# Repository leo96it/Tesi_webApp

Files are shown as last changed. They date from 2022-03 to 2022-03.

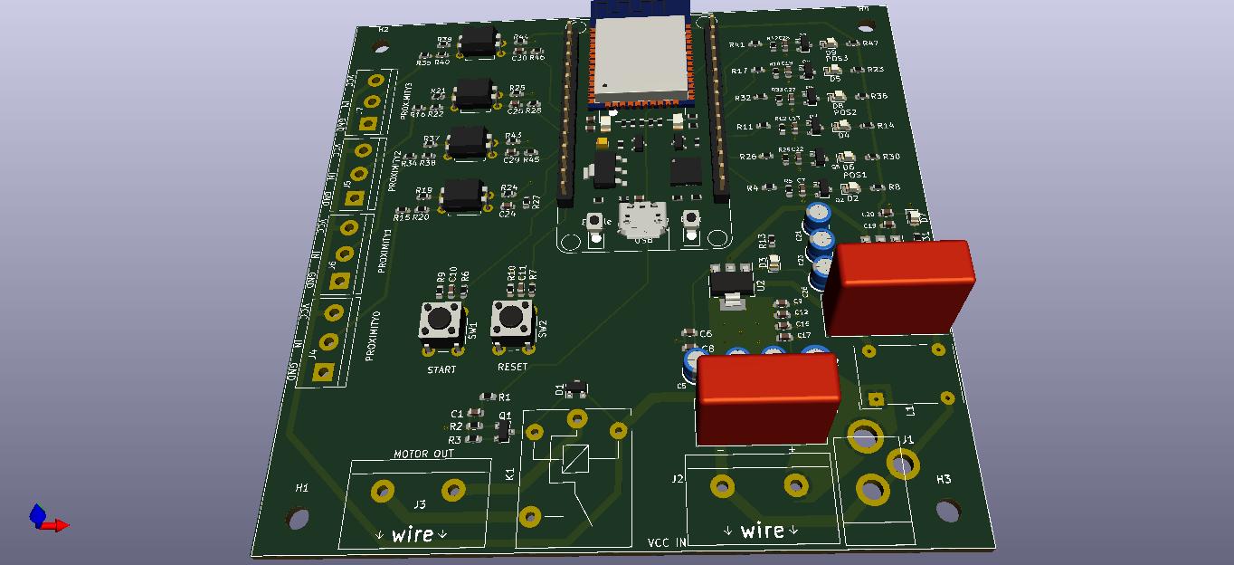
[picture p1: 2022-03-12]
Hardware/ESP32_client/ESP32_client_pcb.jpg

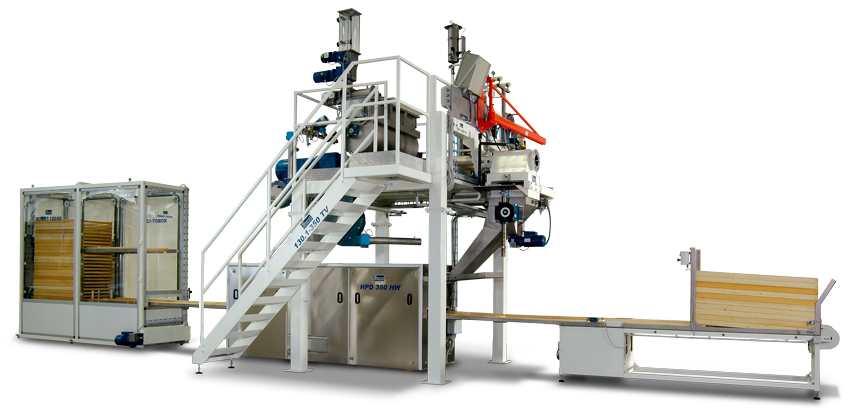
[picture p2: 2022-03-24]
Frontend/angular-app/src/assets/machineryImage/005fewe.png

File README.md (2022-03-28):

# Tesi_webApp

This project was made for the degree in computer engineering at Uninettuno.
It consist of a web server with a backend server, a mysql database and frontend web site. The server receive data from several hardware clients, based on ESP8266 or ESP32 microcontroller.

## Hardware - build with Arduino IDE v1.8.5 and KiCad v5

To run the hardware part, first you need to insert your wifi `SSID` and `password`, then you need to change the `serverURL` variable to match your local IP address.
Finally you can boot the firmware onto the ESP8266 devboard.
ATTENTION: the Arduino IDE require the download of card manager for ESP32 and ESP8266.

## Database - build with MySQL v8.0.28

Download MySQL with the MySQL installer (Windows) from:  https://dev.mysql.com/downloads/installer/.
Create the database called `ESP32_plant1` to match the variable `dbname` in config.json (backend).

## Server - build with NodeJS v14.17.5

Download all the module with `npm i` and start the MYSQL80 system variable. Then run `npm start`.

## Frontend - build with Angular CLI v13.0.3, NPM 6.14.14 and Grafana

First you need to set the Grafana dashboard, follow the PDF file `Elaborato finale - Barea Leonardo` in Extras folder, for the procedure and `query-Grafana` in Database folder for the query from Grafana to MySQL.
Run `ng serve` for a dev server. Navigate to `http://localhost:4200/`. The app will automatically reload if you change any of the source files.

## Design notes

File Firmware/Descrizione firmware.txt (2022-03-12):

Simulazione di uno scenario industriale, con sensori vari.

1. Ad inzio linea è presente un proximity che rileva la presenza o meno del pezzo

2. L'avvia del ciclo di produzione della linea è fatto tramite pulsante START

3. Per ogni stazione sarà presente un proximity per rilevare se il pezzo è arrivato nella stazione ed iniziare quindi la lavorazione

4. La lavorazione è attualmente simulata con un generatore di numeri casuali, il quale simula un PASS/FAIL della lavorazione 

5. In ogni stazione saranno presenti 2 led, verde (tutto ok) e rosso (lavorazione con errori)

6. I led verdi lampeggerenno, tutti: se il pezzo si trova nella postazione 0, ultimi 2: se il pezzo si trova nella postazione 1, solo ultimo: se il pezzo si trova nella postazione 2, nessuno: se il pezzo ha terminato tutto il ciclo e ritorna nella postazione 0.
Ogni volta che il pezzo attraversa una postazione il relativo led diventerà verde fisso se la lavorazione è andata a buon fine o rosso fisso (con relativo blocco impianto) se c'è stato qualche errore

7. Se la lavorazione va in errore si prevede che l'operatore sistemi l'errore e poi tramite pulsante RESET faccia ripartire l'impianto

8. I dati vengono inviati al server ad ogni PASS/FAIL oppure all'uscita del pezzo dalla linea

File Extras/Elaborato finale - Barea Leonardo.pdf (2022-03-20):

## UNIVERSITÀ TELEMATICA INTERNAZIONALE

## UNINETTUNO

## FACOLTÀ DI INGEGNERIA

## Corso di Laurea Triennale in

## Ingegneria Informatica

## ELABORATO FINALE

in

## Ingegneria del software e programmazione ad oggetti

## Monitoraggio di sistemi di produzione industriale, in ambito industria 4.0, attraverso dispositivi IoT

RELATORE | CANDIDATO
Prof.ssa Patrizia Grifoni | Leonardo Barea

### CORRELATORE Prof. Mauro Mazzei

### ANNO ACCADEMICO 2020/2021

i

ii

Con la presente volevo spendere qualche riga per ringraziare tutti coloro che mi sono stati vicini e mi hanno supportato in questo lungo percorso durato tre anni fatto di fatiche e gioie che hanno portato oggi a diventare ciò che sono.

Prima di tutti, vorrei ringraziare la mia compagna Elena che mi ha supportato lungo tutto il percorso, aiutandomi e condividendo insieme a me le gioie degli esiti degli esami e trovando sempre le parole giuste per supportarmi durante i momenti più duri. Grazie a te ho imparato che ogni esame può essere superato, anche quando sembra una montagna insormontabile.

Un ringraziamento va anche alla mia famiglia per avermi sostenuto nella decisione di intraprendere questo percorso di studio e portarlo a termine nel migliore dei modi.

Infine vorrei ringraziare due colleghi di corso, Nicholas e Giampiero, i quali hanno fornito un preziosissimo aiuto alla realizzazione del progetto e con i quali ho avuto il piacere di studiare assieme, portando a casa risultati oltre le aspettative.

Questo percorso mi ha permesso di ritrovare la voglia di studiare, la voglia di imparare, ma soprattutto mi ha permesso di capire che con forza e tanta volontà anche le cose più difficili possono essere superate.

iii

## Indice

iv

v

## Sommario

L’industria nel corso degli anni è stata oggetto di diverse innovazioni, ed insieme ad altri settori,

l’industria riveste un ruolo fondamentale nella vita di ogni persona, direttamente o

indirettamente.

Allo stesso modo l’informatica, settore molto più “giovane” rispetto all’industria, è uno tra quelli più importanti al giorno d’oggi. È il settore che ha visto un incremento esponenziale

dell’innovazione, con una pendenza più ripida rispetto a tutti gli altri settori, passando dalla

gestione di pochi bit negli anni ’50 a milioni di miliardi di bit di oggi.

Questo sviluppo così repentino ha portato l’informatica ad evolversi non solo in verticale (dove

ad un certo punto lo sviluppo è, per forza di cose, rallentato), ma anche in maniera, così

trasversale, da arrivare in tutti i settori, uno tra tutti l’industria.

L’informatica applicata agli oggetti prende il nome di IoT (Internet of Things), ovvero internet

delle cose, mentre in particolare l’informatica legata all’industria prende il nome di IIoT

(Industrial Internet of Things), dall’altro lato invece l’industria che integra sistemi cibernetici,

informatici e connessi, si racchiude all’interno dell’ Industria 4.0.

L’industria 4.0 si basa sul fatto che, se è possibile “connettere” un oggetto di uso comune, come

un orologio, una sveglia, allo stesso modo è possibile connettere anche sistemi più complessi

come, macchinari, robot e utensili.

Il progetto prevede la creazione di un web server completo, fornito di una parte back-end ed una

front-end, per il monitoraggio di impianti di produzione, attraverso un sito dedicato.

Il seguente elaborato ha lo scopo di analizzare nel dettaglio l’implementazione pratica e gli

aspetti fondamentali delle tecnologie utilizzate, nonché fornire un valido supporto al lettore per

la comprensione e la riproduzione dello stesso.

Nel secondo capitolo vengono trattate le tecnologie software utilizzate per la realizzazione del

progetto. In particolare vengono trattati i software utilizzati per ogni livello applicativo, partendo

dall’hardware è stato utilizzato Kicad, software open source, per la schematizzazione e

realizzazione di schede elettroniche (PCB) con strumenti professionali. Permette di generare dei

file Gerber (file contenenti le posizioni dei fori, del layout, dei componenti, il numero di

layer…), con i quali il produttore di schede è in grado di poter poi produrre i PCB.

Arduino IDE, ambiente di sviluppo per l’omonima scheda di sviluppo (o similari), anch’esso

open source, permette la programmazione di microcontrollori della famiglia Atmel o Espressif

vi

(come nel caso del progetto in essere), attraverso un’interfaccia semplice con il supporto di una

community online molto attiva, in linguaggio Wiring.

NodeJS è la piattaforma utilizzata per lo sviluppo del livello back-end, il server. Anch’esso

open-source, sviluppato in tempi recenti, permette, attraverso il motore V8 di Chrome,

l’esecuzione di codice Javascript al di fuori del browser.

MySQL è il DBMS (Data Base Management System) utilizzato per la memorizzazione dei dati

di produzione. Si avvale di tabelle, attraverso le quali è possibile instaurare delle relazioni

semantiche tra diversi attributi della tabella stessa o di altre tabelle.

Angular, framework anch’esso opensource, per la realizzazione di applicativi web, basati su

architettura a pagina singola (single page application), attraverso la quale tutto risiede in

un’unica pagina ed è il contenuto all’interno di essa a cambiare e non la pagina stessa. In questo

modo è possibile creare applicazioni più veloci dove soltanto alcune parti della pagina cambiano

mentre le altre rimangono invariate.

Github è un servizio di repositoring, gratuito, all’interno del quale è possibile caricare del

software (o anche solo parti di codice), per lavorare in team, rendere pubblico il codice scritto, o

più semplicemente avere un “contenitore” (repository) remoto del proprio codice, accessibile

dovunque. Con Github è possibile anche tenere traccia delle modifiche.

Grafana, applicazione web gratuita, permette di accedere a diversi database o sistemi di backend

per fornire una rappresentazione grafica dei dati in essi contenuti.

Grafana permette di accedere direttamente al database attraverso delle query, permette di

scegliere tra diversi grafici molto accattivanti e ben fatti e lavorare sul layout di questi.

Nel terzo capitolo è stato discusso lo scenario d’uso e le caratteristiche del progetto, in

particolare il progetto è stato articolato in modo da essere quanto più scalabile possibile e

permette di agire su ogni livello implementativo senza dover necessariamente stravolgere gli altri

livelli. Una delle caratteristiche principali, è stata proprio la possibilità di rendere il progetto

open-source e accessibile a chiunque lo volesse consultare e migliorare, il tutto accessibile sul

repository pubblico su Github.

Gli scopi principali del progetto sono quelli di garantire manutenzione, efficienza e risparmio. Il

tutto è reso possibile dalle scelte progettuali effettuate, dal know-how acquisito in ambito

industriale e dalle problematiche riscontrate in macchinari di produzione industriale.

vii

Il fine è appunto quello di garantire un maggior controllo sulla produzione per poter intervenire

prontamente sui problemi che si presentano ed avere quindi costi di produzione più bassi, minor

numero di fermi macchina, maggiore autonomia e programmazione delle manutenzioni.

Nei capitoli successivi vengono descritti nel dettaglio le parti di codice più salienti, necessarie

per la comprensione del funzionamento del progetto stesso, il quale prevede più livelli

implementativi:

Il primo è quello hardware, dove un microcontrollore si occupa della raccolta dei dati di

produzione ed invia il tutto in formato JSON al server tramite il protocollo HTTP, il server

recupera i dati, li spacchetta e salva ogni dato ricevuto in un database MySQL. Il sito costruito in

Angular effettuerà delle richieste cicliche (polling) al server il quale risponderà fornendo i dati di

produzione che verranno successivamente mostrati attraverso un browser. Questi dati saranno

visualizzabili in tempo reale, con questi che vengono aggiornati costantemente, oppure sarà

possibile visionarli in uno storico con grafici e diagrammi temporali.

Le possibilità di sviluppo di questo progetto sono pressoché illimitate, per come è stato costruito,

il sito può essere integrato con una sezione di login, è possibile implementare un sistema di

notifica Telegram o mail, è possibile standardizzare il firmware in modo che questo possa

comunicare attraverso un protocollo standard, il MODBUS RTU, con i PLC installati sui

macchinari, in questo modo è possibile monitorare la produzione senza nemmeno dover

modificare l’impianto od i macchinari già presenti.

L’informatica, rende oggi possibile molte delle cose che un tempo erano solo utopie, basta

soltanto un po’ di fantasia, di spirito critico e di tanto studio!

## 1 Introduzione

Negli ultimi anni lo sviluppo legato ad internet ed alle aziende ICT ha visto una crescita non più

soltanto verticale, ovvero legato a determinati campi, ma anche orizzontale, vedendo settori

come l’agricoltura e l’industria sempre più a stretto contatto con quello che è il mondo di

internet. Un po’ per moda, un po’ per scopi effettivamente pratici, ad oggi le aziende stanno

cercando di mettersi al pari con quello che è il progresso tecnologico.

A favore di questo processo di transizione, il Governo, ha messo e sta mettendo, in atto delle

misure volte ad agevolare le aziende stesse ed in particolare le PMI, le quali costituiscono la gran

parte delle aziende italiane, che senza agevolazioni o incentivi difficilmente sarebbero propense

(o meglio in grado) di affrontare i costi di un tale cambiamento. Di fatti si è di fronte a quella che

ormai viene definita 4° rivoluzione industriale.

Negli ultimi 15 anni, si è visto un’importante balzo in avanti anche per quanto riguarda le

tecnologie di internet. Sono infatti nati numerosi framework e linguaggi che prima non

esistevano e con loro si sono quindi incrementate le possibilità di nuovi sviluppi. Basti pensare

che senza javascript le pagine sarebbero ancora statiche o con limitata dinamicità.

L’IoT (Internet of Things) o meglio definito “internet delle cose” è alla base di questo sviluppo e

questo progresso tecnologico che vede interessati sempre più settori e campi d’applicazione.

Ormai risulta veramente economico implementare, a livello hardware, un modulo

Bluetooth/WiFi, per cui ogni dispositivo, elettrodomestico, capo d’abbigliamento ecc ad oggi

può essere connesso ad internet.

L’IoT, quindi, è approdato anche nell’industria e nella robotica al fine di migliorare ed

incrementare la produzione, nonché per garantire una gestione più accurata della qualità.

Lo scopo del progetto è quello di mostrare un esempio di applicazione dell’IoT in ambito

industriale.

Il progetto prevede tutti i livelli d’implementazione di un caso reale di una linea di produzione

industriale con più postazioni, dove l’operatore inserisce il pezzo grezzo da lavorare nella prima

postazione e preme il pulsante di start. Da quel momento vengono azionati i nastri automatici

che porteranno il pezzo da lavorare nelle varie postazioni. Ad ogni postazione sono presenti una

serie di sensori, attuatori e attrezzi per la lavorazione del pezzo e per il controllo dei vari

parametri di lavorazione (quote, quantità di olio, temperatura…).

Quindi passando all’hardware, si è progettato e implementato il circuito elettronico al quale è

collegato il microcontrollore ESP32 (client) il quale, attraverso un firmware apposito, elabora i

diversi dati di produzione/posizione del pezzo e parametri di lavorazione e li invia al server

NodeJS attraverso una chiamata HTTP POST.

Successivamente il server che è in ascolto, recepisce il dato inviato da ESP32 (nel caso di più

ESP32 ognuno sarà un client e tutti invieranno i dati allo stesso indirizzo del server) ed andrà a

salvare questi dati in un database MySQL.

Per la parte di front-end è stato utilizzato il framework Angular, il quale attraverso un’operazione

di polling effettua delle chiamate HTTP GET cicliche al server per tenere i dati costantemente

aggiornati. Infine, nella parte di front-end è stato utilizzata Grafana, un’applicazione web per la

creazione di grafici, la quale effettua direttamente delle query al database per i dati da graficare.

### 1.1 Industria 4.0

Questo rappresenta il tema principale dell’elaborato e rappresenta anche uno dei temi principali

dell’innovazione tecnologica che l’Italia sta portando avanti con la transizione 4.0.

Con industria 4.0 si va ad identificare quella che viene chiamata quarta rivoluzione industriale,

ovvero quella che integra internet ai processi produttivi al fine di migliorare le condizioni di

lavoro, creare nuovi modelli di business, aumentare la produttività degli impianti e migliorare la

qualità dei prodotti.

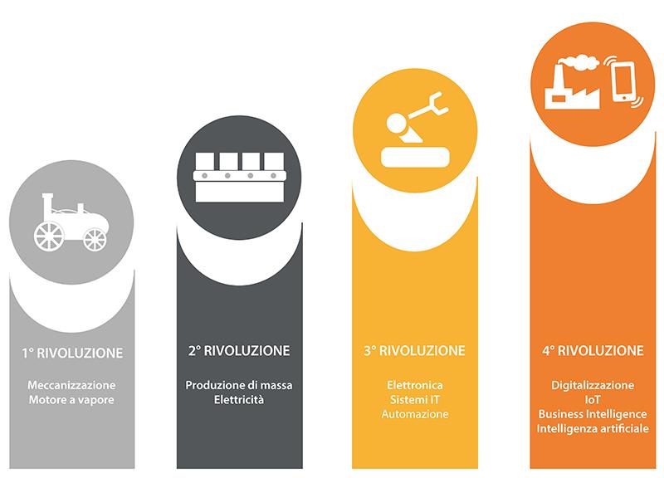
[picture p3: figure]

Figura 1.1: Le quattro rivoluzioni industriali nella storia

### 1.1.1 Industria 4.0 nel mondo

A livello mondiale, il MISE, cita alcune iniziative messe in atto da diversi paesi.

La Francia, ad esempio, ha messo in atto una serie di finanziamenti, prestiti agevolati ed

incentivi per consentire alle aziende di effettuare la transizione.

In Germania, oltre ai finanziamenti alle imprese, è in fase di approvazione dal Governo una serie

di agevolazioni per investire nelle start-up, spesso iniziatrici di innovazioni tecnologiche

importanti.

In Olanda si sta lavorando ad un approccio “network centric” in cui il sistema industriale

tradizionale si combina con le organizzazioni scientifiche e di ricerca nonché con le istituzioni

Governative.

### 1.1.2 Industria 4.0 in Italia

A livello internazionale invece, il Governo, ha dettato una serie di linee guida per consentire alle

imprese di effettuare la transizione tecnologica nel migliore dei modi:

- Neutralità tecnologica
- Operare con azioni orizzontali e non di settore (verticali)
- Orientare strumenti esistenti per favorire il salto tecnologico

Tutte linee guida, basate sulle caratteristiche del settore industriale italiano.

In particolare come nel resto del mondo il piano nazionale prevede degli investimenti alle imprese private ed alle start-up, ma non solo, in quanto lo sviluppo in sé parte dalla scuola. È

così che il Governo Italiano, investe nelle competenze, quindi in progetti di Scuola Digitale,

percorsi Universitari e ITS, dottorati e ricerca…, tutto questo rientra nel Piano Nazionale

Industria 4.0.

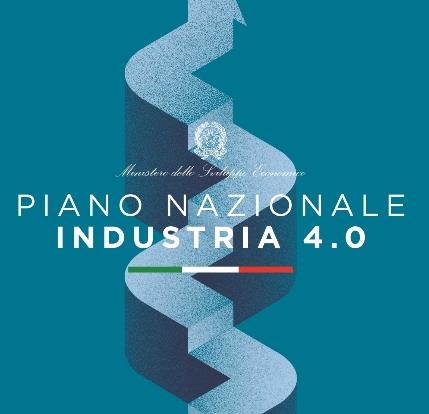
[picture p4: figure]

Figura 1.2: Prima pagina della presentazione "Piano Nazionale Industria 4.0"

### 1.2 Web application

L’altro tema principale di questo elaborato sono le web application. Molto brevemente una web

application, come dice il nome, è un’applicazione (o un insieme di applicazioni) accessibile via

web, quindi attraverso internet.

La maggior parte di queste applicazioni utilizzano come terminali i browser, i quali permettono

lo scambio di dati attraverso protocolli di rete standard, con server remoti i quali contengono i

dati e le pagine dell’applicazione stessa.

Le web application stanno, via a via, diventando sempre più presenti nell’immaginario collettivo

e questo è dovuto al fatto che queste non devono avere un supporto per una specifica

piattaforma, bensì basta un accesso ad internet, un browser ed il gioco è fatto.

In genere una web app si compone di più livelli, per renderla quanto più scalabile possibile,

generalmente si trova un front-end, che è il livello più alto, in cui i dati vengono mostrati

all’utente con l’utilizzo di grafica, immagini, video e suoni secondo lo stile definito dal designer.

A livello più basso troviamo un back-end, che è il nodo centrale, quella parte che consente la

gestione e la manipolazione dei dati e si occupa di gestire le richieste del front-end. Facendo

riferimento a questo elaborato, si trova anche un livello di archiviazione, in cui un database

memorizza tutti i dati che verranno inviati e gestiti dal back-end.

### 1.2.1 Protocollo HTTP

HTTP, ovvero Hyper Text Transfer Protocol, è il protocollo principale per lo scambio di dati sul web. È un linguaggio di testo (ipertesto) che lavora con un’architettura di tipo client-server, in

cui un client effettua una richiesta (request) al server e questo gli risponde con la risorsa cercata

(response).

Una richiesta HTTP generalmente è composta in questo modo:

Figura 1.3: Struttura di una richiesta HTTP

Dove l’URI (Uniform Resource Identifier) è una stringa che identifica in modo univoco una

risorsa.

Il metodo (method), è la parte più importante. Consente di specificare il tipo di richiesta da

effettuare al server da parte del front-end (ad esempio). Qui vengono citati soltanto alcuni dei

metodi presenti e più nel dettaglio quelli utilizzati nel progetto:

- GET: è il metodo più utilizzato dal front-end e serve per recuperare una risorsa dal

server. Nel progetto è utilizzato per la richiesta dei dati da visualizzare sulla pagina web.

- POST: è un metodo che serve per inviare delle risorse al server. Potrebbe essere utilizzato

per inviare i dati di un form dal front-end al server, ma nel progetto è stato utilizzato per

inviare i dati dalla scheda hardware al server.

- DELETE: è un metodo utilizzato per eliminare una risorsa dal server (nel progetto non

viene utilizzato).

Version rappresenta la versione del protocollo HTTP utilizzato. Ad oggi la versione più recente è

la 3.0, risalente al 2018/2019.

L’header contiene una serie di meta informazioni utili per il coordinamento tra client e server

(come ad esempio lo status code, la lunghezza del pacchetto…).

Infine body è il corpo della richiesta HTTP, ovvero quella che conterrà le informazioni.

### 1.2.2 Client-Server

La maggior parte delle applicazioni web, si basano sul modello architetturale client-server, in cui

uno o più client si collegano ad internet e tramite un determinato protocollo (nel progetto è stato

utilizzato il protocollo HTTP visto precedentemente) effettuano delle richieste al server e questo

vi risponde.

Esistono due tipologie di implementazione di un modello client-server in funzione del numero di

livelli su cui l’applicazione è costruita:

- 2-tier: basata su due livelli, il client si connette direttamente con il server;
- 3-tier: nel client sono presenti due livelli, uno che si occupa di gestire la comunicazione

con il server, mentre la visualizzazione dei dati è in un livello a parte (livello thin client).

Figura 1.4: Struttura modello client - server

### 1.3 Internet of things

Internet of things tradotto sta per “internet delle cose”, è quella categoria di oggetti di un

qualsiasi ambito, che in qualche modo sono “connessi”, ovvero presentano una connessione ad

internet.

Questi dispositivi ormai si trovano in ogni cosa, dall’agricoltura, alla domotica, nell’automotive

e nell’industria. Con pochi Euro o addirittura meno è possibile acquistare delle schede di

sviluppo (development board) con a bordo un microcontrollore e dei componenti in grado di

collegarsi al wifi e quindi di inviare e ricevere dati attraverso internet.

La particolarità di questi dispositivi è che sono davvero piccolissimi, alcuni di questi sono grandi

come una moneta e questo permette di integrarli in qualsiasi dispositivo, come orologi, scarpe,

auto e tutto ciò che si vuole.

Il basso costo e le dimensioni ridotte sono i fattori che hanno contribuito alla diffusione di questi

dispositivi e quindi l’integrazione in diversi oggetti.

### 1.3.1 Industrial Internet of Things

Come si può ben capire, con Industrial Internet of Things (I-IoT) si identifica quella branca

dell’IoT legata al mondo industriale, cercando di rendere più efficienti i vari processi.

Le applicazioni, in campo industriale, di internet, sono molteplici, come riportato in [14]:

- Smart Factory: controllo avanzamento produzione (che è lo scopo principale del

progetto), manutenzione, movimentazione materiali, controllo qualità;

- Smart Logistics: tracciabilità / monitoraggio della filiera tramite tag RFId (Radio-

Frequency Identification) e sensoristica, gestione delle flotte (es. tramite GPS);

- Smart Lifecycle: miglioramento del processo di sviluppo nuovi prodotti (es. tramite dati

provenienti da versioni precedenti dei prodotti connessi).

Quindi integrandosi ai tradizionali modelli di produzione i dispositivi IoT riescono ad apportare

diversi reali benefici. In Italia, purtroppo, nonostante il Governo abbia finanziato fondi a

sostegno della transizione tecnologica, poche sono le PMI che ad oggi hanno effettivamente

avviato progetti di questo tipo, a differenza invece delle grandi imprese che da questo punto di

vista sono più istruite.

## 2 Panoramica software e framework

Qui di seguito verranno affrontati a livello teorico i principali software e framework utilizzati per

portare a termine il progetto. Per la spiegazione dettagliata dell’uso che se ne è fatto di questi si

rimanda al capitolo successivo.

### 2.1 Kicad

Kicad è un software open source gratuito per la progettazione di circuiti elettronici. Integra al

suo interno un editor per schematici (Eeschema), dove è possibile disegnare il proprio schema

elettronico con migliaia di componenti già presenti in decine di librerie, ma se il componente che

si vuole aggiungere non è presente in queste è possibile creare il componente o la libreria di componenti custom in pochi semplici passi come è riportato nei manuali ufficiali [16] e [17]

scaricabili nella sezione “Documentation” del sito [15].

È presente poi un editor PCB (Pcbnew), il quale grazie alle impronte dei componenti, sempre

presenti nelle diverse librerie, è possibile definire il layout del PCB per come dovrà poi essere

prodotto.

Per aiutare durante la fase di prototipazione, sul software è anche presente un tool per la

visualizzazione in 3D dello stampato con i componenti posizionati come da specifiche di chi lo

progetta. Questo è utile per vedere se l’impronta del componente scelto corrisponde con il

componente in nostro possesso o meglio per analizzare gli ingombri della scheda finita.

Un'altra funzionalità molto interessante è quella messa a disposizione da Eeschema, dove è

possibile simulare il circuito disegnato ed effettuare un test delle regole elettriche, grazie al

simulatore SPICE integrato.

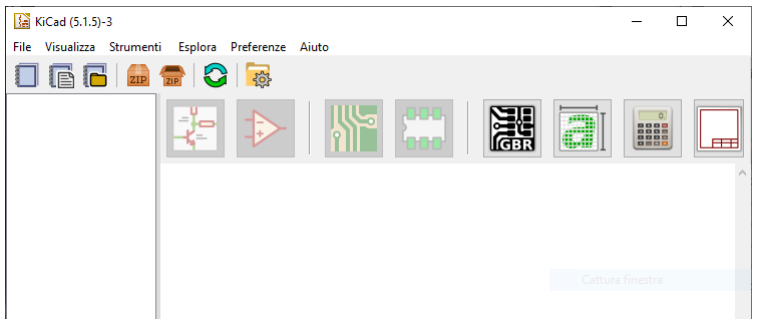
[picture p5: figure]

Figura 2.1: Schermata Kicad

### 2.2 Arduino IDE

L’IDE (Integrated Development Environment) è un ambiente di sviluppo integrato in cui è

possibile scrivere del codice ed usufruire di diversi tool per lo sviluppo.

L’IDE di Arduino è un software scritto in Java, che si utilizza per scrivere codice e programmare

microcontrollori compatibili con i gestori delle schede installate.

All’interno dell’IDE troviamo come prima cosa una parte del codice già precompilato e questo è

sicuramente di supporto ai neofiti ma anche a programmatori più esperti che vogliono evitare di

scrivere pezzi di codice ridondante ad ogni nuovo progetto.

Un altro aspetto interessante accanto al gestore di schede è la possibilità di installare librerie

direttamente dall’IDE, cercandole per nome e leggendo la descrizione delle funzioni e le schede

con cui è compatibile, avendo inoltre la possibilità di selezionare la versione che più si desidera.

Il linguaggio utilizzato per sviluppare su piattaforma Arduino è un derivato del C/C++, il Wiring,

semplificato dalle librerie native e questo permette uno sviluppo veloce con una curva di

apprendimento relativamente breve, questo è dovuto anche al fatto che le istruzioni da utilizzare

prevedono un approccio di alto livello senza dover necessariamente conoscere la struttura fisica

del microcontrollore (registri, banchi di memoria…), in quanto tutto ciò è gestito in automatico

dall’IDE stesso e dalle librerie.

Figura 2.2: Schermata Arduino IDE

### 2.3 NodeJS

NodeJS è una piattaforma open-source e cross-platform di sviluppo in cui è possibile eseguire

del codice Javascript utilizzando il paradigma della programmazione ad oggetti.

Node è nato nel 2009 ed il suo successo è dovuto al fatto che per la prima volta, Javascript è

stato utilizzato al di fuori del web. Questo è dovuto al fatto che Node implementa il motore V8 di

Chrome, un motore Javascript open-source ad alte performance, scritto in C++, in grado di

compilare ed eseguire codice Javascript anche al di fuori del browser.

Un altro motivo di successo di Node è dovuto al fatto che è stato concepito come un gestore

asincrono di eventi, infatti ad ogni evento viene richiamata una funzione di callback e questo permette di ottimizzare l’esecuzione di Node stesso, il quale rimarrà in attesa fino a quando

l’evento a cui si era fatta sottoscrizione non emette una notifica, solo in questo caso Node torna

operativo ed esegue le funzioni di callback assegnate, tutto ciò che accade prima è delegato al

sistema operativo, in modo tale da lasciar libera l’esecuzione di Node per poter gestire eventuali

altri eventi. Questa gestione degli eventi è definita non bloccante. Grazie a queste caratteristiche

Node è particolarmente adatto a costruire sistemi scalabili e orientati agli eventi.

Nonostante Node sia single-thread, orientato agli eventi e non bloccante, è concesso l’utilizzo di

processi figlio utilizzando le API fork e allo stesso modo è possibile definire del codice

bloccante utilizzando metodi sincroni (ad esempio per la lettura di file di piccole dimensioni o

per ragioni di sequenzialità di esecuzione), però essendo un ambiente fortemente sviluppato per

applicazioni real-time (sistemi di notifiche push, chat, pubblicazione di dati) l’utilizzo di metodi

sincroni viene poco utilizzato o meglio viene utilizzato, in alternativa, con sistemi multi-thread.

Node si compone di innumerevoli moduli, che non sono altro che del codice riusabile, come

delle librerie che espongono dei metodi che si possono richiamare dopo averli importati, questi si

dividono in tre categorie:

- Interni: scritti direttamente dallo sviluppatore
- Built-in: costruiti internamente a Node
- Esterni: sviluppati da terzi (richiedono di essere installati)

I moduli esterni si possono trovare tutti racchiusi all’interno di npm (Node Package Manager), il

quale è il più grande contenitore di pacchetti al mondo ed è già installato in Node e grazie alla

CLI (Command Line Interface) è possibile, appunto, importare pacchetti presenti in npm scritti

da sviluppatori di tutto il mondo. Oltre ai moduli con npm è possibile anche importare dei

framework, come react ad esempio.

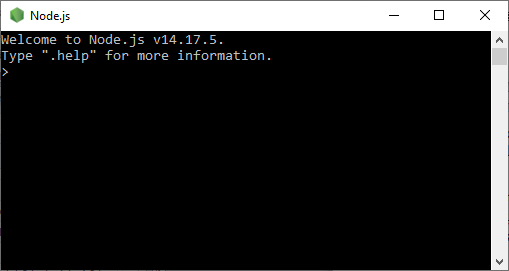
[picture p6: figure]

Figura 2.3: Schermata Node.js

### 2.4 MySQL

MySQL è un software che supporta un veloce, multithreaded, multi utente e robusto server

database SQL (Structured Query Language). Il server di MySQL è adatto all’utilizzo con sistemi

con un alto carico di produzione.

MySQL è uno dei RDBMS (Relational DataBase Management System) open-source più diffuso

ed utilizzato al mondo, era inizialmente di proprietà dell’omonima azienda, ma poi è stato

acquisito da Oracle, anch’essa produttrice di DBMS, la quale incorpora MySQL in alcuni dei

suoi prodotti.

MySQL è un database relazionale, il che vuol dire che è basato sul concetto matematico/logico

di relazione, secondo il quale tutti i dati sono rappresentati da relazioni, infatti vige il modello

ER (Entità-Relazione) per la costruzione delle tabelle. Questo permette di associare più dati tra

di loro e di trovare un determinato dato in funzione della relazione che questo ha con altri dati.

Con la nuova versione 8.0 di MySQL, ad oggi disponibile, si integra non solo l’SQL ma anche il

NoSQL (Not Only SQL), che prima era delegata soltanto ad altri DBMS non relazionali, con

l’eccezione che MySQL aggiunge al NoSQL le proprietà ACID (Atomicity, Consistency,

Isolation e Durability) alle quali soltanto i DB relazionali facevano riferimento, questo permette

di unire la robustezza e l’affidabilità di un DB relazionale con la semplicità, la funzionalità e la

scalabilità di un DB NoSQL per creare applicazioni sempre più performanti.

Figura 2.4: Schermata MySQL Workbench

### 2.5 Angular

Angular è un framework che permette di costruire applicazioni mono-pagina efficienti e sofisticate. È scritto in TypeScript ed include:

- Framework basato sui componenti, questo permette di creare applicazioni modulari e

scalabili, scrivendo poco codice per ogni componente per poterlo riutilizzare in più

applicazioni

- Una vasta varietà di librerie che coprono molte funzionalità disponibili (routing, forms,

http…)

Con Angular si possono scrivere applicazioni front-end, mono-pagina, il che vuol dire che tutto

il sito creato risiederà su un’unica pagina. Questo permette all’applicazione di essere molto

veloce e reattiva, in quanto tutte le risorse (tranne i dati) verranno caricati tutti in una sola volta

all’apertura del sito, quindi le uniche richieste che verranno fatte al server successivamente,

saranno solo per i dati.

Un componente Angular si compone essenzialmente di 4 file:

- Component.html: è il template del componente e qui si va a scrivere il codice HTML

relativo al componente che si sta creando. In aggiunta ai tag classici, con Angular, è

possibile inserire dei costrutti come if, for e switch direttamente nell’HTML;

- Component.css: è il foglio di stile del componente, qui è possibile andare a definire le

regole di stile. Questo non deve essere importato nell’HTML in quanto già collegato

tramite il file typescript;

- Component.ts: è il file typescript del componente, quel file dove è possibile definire il

codice operativo (costrutti, metodi, variabili…) per il componente in linguaggio

typescript e javascript, oltre che importare i moduli necessari per il funzionamento del

codice e dei metodi usati;

- Component.spec.ts: è un file di test per il componente;

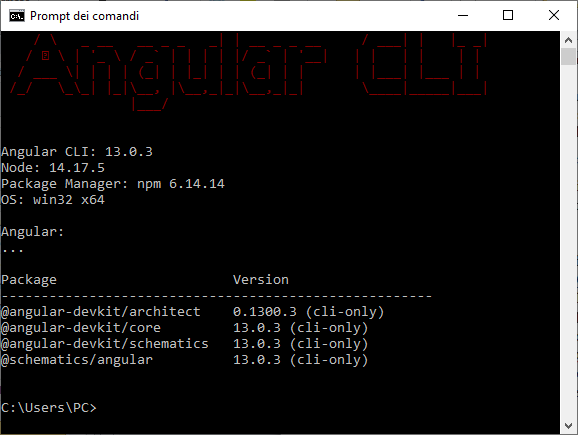
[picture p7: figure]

Figura 2.5: Schermata Angular CLI

### 2.6 GitHub

Per garantire una maggiore esportabilità ed un maggiore controllo degli aggiornamenti si è

deciso di includere il progetto in un repository locale con Git ed esportarlo anche su un

repository remoto con GitHub.

Github è servizio di repositoring per progetti software. È possibile pubblicare progetti, software

o anche soltanto parti di codice all’interno di repository privati o pubblici, tenere traccia degli

aggiornamenti (aggiungendo ad esempio dei messaggi), inserire un file README contenente

informazioni di supporto per l’esecuzione del codice.

All’interno del repository è possibile anche vedere i linguaggi utilizzati per la scrittura del codice

e la loro percentuale di utilizzo, nonché tutti gli utenti che hanno apportato dei contributi o hanno

segnalato dei bug.

Il link al repository pubblico GitHub del progetto si trova al seguente link:

https://github.com/leo96it/Tesi_webApp

Per collegare il progetto con il proprio repository è necessario prima di tutto aver creato un

account su GitHub, successivamente è necessario scaricare ed installare Git dalla relativa pagina

di download presente al link in appendice [b].

Una volta fatto questo è necessario creare una cartella, nella directory, dove si andrà ad

importare il progetto. Fatto questo con Git CMD (Git Command line, ovvero terminale a riga di

comando di Git) ci si posiziona all’interno della cartella appena creata e si eseguono i seguenti

comandi:

Þ git init //inizializzazione repository locale

Þ git clone “https://github.com/leo96it/Tesi_webApp”

//clonazione repository remoto

Þ git pull Tesi_webApp main // importazione progetto

Con il progetto ora nel repository locale è possibile eseguirlo seguendo le indicazioni contenute

nel file README.md.

### 2.7 Grafana

Grafana è un’applicazione web open-source che permette di richiedere dei dati direttamente ad

un server od ad un database e successivamente di mostrarli nella tipologia di grafico scelta. Sono

supportate le connessioni con pressoché tutti i database più conosciuti e la procedura di

connessione con il database scelto è molto semplice ed intuitiva.

Esistono due versioni per l’accesso ai grafici di Grafana, la versione cloud ed una versione

installabile ed accessibile collegandosi all’indirizzo di default http://localhost:3000/ (è possibile

modificare la porta 3000 con quella che si vuole, andando a modificare il parametro

http_port nel file defaults.ini all’interno della cartella grafana/conf).

Con Grafana è possibile creare delle dashboard, all’interno delle quali è possibile scegliere tra

una spiccata varietà di grafici (grafici a torta, istogrammi, grafici a barre, tabelle, grafici

temporali…).

Per prelevare i dati da un database, è necessario selezionare il database desiderato nella sezione

“datasource”, fornire i dati di accesso al database e connettersi ad esso. Successivamente sarà

possibile creare la dashboard andando a scegliere la tipologia di grafico ed importare i dati dal

DB effettuando delle query SQL (nel caso di MySQL).

Per i grafici basati su una serie temporale, sarà necessario che sia presente sul DB anche una

colonna con dati di tipo DATETIME (o similari). Per la visualizzazione dell’arco temporale si

può scegliere tra quelli disponibili, oppure crearne di personalizzati. In alternativa è possibile anche agire direttamente con il mouse per ingrandire o diminuire un’area e quindi anche il

relativo specchio temporale.

Grafana è in grado di creare alert, che possono essere di solo tipo visivo evidenziando le

misurazioni che non rispettano i criteri dettati dall'utente, o attraverso l'emissione di eventi

personalizzati, come per esempio un messaggio e-mail o attraverso Telegram.

Figura 2.6: Schermata esempio Grafana

## 3 Caso di studio

### 3.1 Scenario d’uso

Il progetto è stato pensato per fornire un valido strumento di feedback per macchinari industriali

e per il loro monitoraggio da remoto.

### 3.1.1 Caratteristiche del progetto

Le caratteristiche del progetto sono:

- Open-source e multipiattaforma: il progetto completo è disponibile su GitHub

gratuitamente, sia per la parte hardware che per la parte software. L’applicativo front-end

può girare su qualsiasi piattaforma sia desktop che mobile in quanto scritta con Angular e

come già spiegato nel capito 2.5 necessita soltanto di un browser ed un accesso ad

internet

- Low cost: per la realizzazione dell’intero progetto, le spese sostenute sono state:
- Prototipazione PCB: 4,87€/5pz prodotta in Cina da JLCPCB.
- Acquisto componenti: in totale 10€ acquistati in parte su Aliexpress, Farnell, RS

ed Ebay. La BOM (Bill Of Materials) è presente nel repository GitHub.

- Minuteria e ferramenta varia: nel progetto il tutto è stato composto

artigianalmente, in uno scenario reale si dovranno prevedere collegamenti

elettrici, involucri e tutto ciò serve per portare i dati dal centro di controllo del

macchinario alla scheda utilizzata nel progetto. Inoltre nel caso di un utilizzo reale

si dovrà procedere con l’iter burocratico per l’utilizzo di apparecchiature

elettroniche autoprodotte.

- Eventuale hosting del progetto su un dominio acquistato (vedi Aruba,

Altervista…)

Tutti i software ed i framework utilizzati sono open-source e gratuiti, pertanto, per il loro

utilizzo, non è previsto il pagamento di nessun canone.

- Scalabile: il progetto si basa interamente sul paradigma Client-Server, per cui dato un

server, questo può gestire le richieste di diversi Client. Quindi definito il server, questo sarà in grado di supportare le richieste di più client front-end (per la visualizzazione dei

dati) e più client fisici, ovvero più schede collegate a diversi macchinari

- Modulare: utilizzando, sia per il front-end che per il back-end, i paradigmi della

programmazione ad oggetti ed un approccio a moduli e componenti, è possibile in

qualsiasi istante aggiungere nuove funzionalità all’applicazione senza dover stravolgere il

progetto (ad esempio, inserimento di login e password, form per il caricamento di nuovi

macchinari e loro caratteristiche…)

### 3.1.2 Focus del progetto

Molto spesso gli enti di certificazione per la qualità richiedo un archivio degli scarti e delle non

conformità, uno degli scopi principali quindi di questo progetto è quello di fornire questo

supporto attraverso il database (in questo caso MySQL). Oltre a questo, gli altri benefici che

un’azienda potrebbe avere dall’utilizzo di questo progetto sono:

- Manutenzione: tramite l’applicativo è possibile tenere traccia dell’usura dei componenti

meccanici di alcuni macchinari (i torni necessitano di un cambio placchette ogni tot pezzi

prodotti)

- Efficienza: è possibile verificare il numero di pezzi prodotti in un’ora, una giornata, o una

settimana ed andare ad agire prontamente quando questa statistica peggiora, o

semplicemente per migliorare la produzione

- Risparmio: nel caso di un corpo macchine molto vasto, è possibile ridurre il numero di

persone che vigilano su di esse, fornendo il responsabile di un tablet dove poter collegarsi

e controllare in tempo reale lo stato delle macchine ed eventualmente indirizzare le

persone giuste per risolvere eventuali problemi meccanici/elettrici tutto da un’unica

postazione mobile.

Questi sono soltanto alcuni dei benefici derivanti da questa tecnologia, altri possibili sviluppi

sono descritti nel capitolo “Conclusioni e sviluppi futuri”.

### 3.2 Panoramica progetto

Nel seguente capitolo si andrà ad analizzare nel dettaglio le scelte progettuali e di sviluppo

intraprese. Nei prossimi capitoli invece, si analizzerà il codice nelle sue parti più salienti,

andando a fare una piccola divagazione sui moduli e sui pacchetti utilizzati.

### 3.2.1 Struttura del progetto

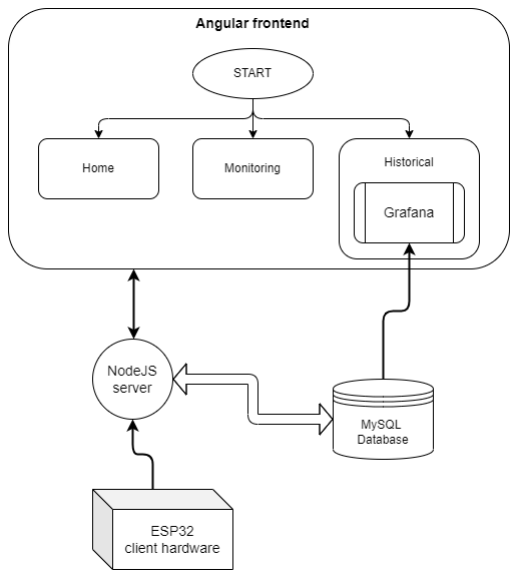
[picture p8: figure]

Figura 3.1: Struttura del progetto

Il progetto si compone di quattro macro sezioni principali:

A. ESP32: questo rappresenta la parte hardware del progetto, è il cuore per la gestione del

macchinario, si compone di una scheda elettronica accessoria per la gestione di motori,

sensori e attrezzature. Nella scheda è installato una dev-board ESP32 con un

microcontrollore che ha lo scopo di gestire l’elettronica ad esso collegata e per effettuare

le chiamate HTTP verso il server e quindi di connettersi ad internet.

B. Server: scritto con NodeJS, ha lo scopo di recepire i dati di produzione dai diversi client

hardware ed instradarli all’interno del database. Il server si occuperà inoltre di

“impacchettare” i dati ricevuti dal client hardware in array pronti da essere spediti al

front-end, quando ne farà richiesta.

C. Database: scelto MySQL come RDBMS, questo si occuperà del salvataggio di tutti i dati

in una tabella, contenente come chiave primaria un ID numerico progressivo e due colonne riportanti la data di creazione della riga e la data di modifica della riga stessa (in

caso la riga non sia stata modificata, la data di modifica sarà uguale a quella di

creazione).

D. Front-end: scritto con Angular, ha lo scopo di garantire un accesso remoto ai dati

contenuti in server e database. Effettua un polling di chiamate GET al server, il quale in

base alla route fornirà i dati di produzione raccolti dai vari client hardware sotto forma di

un array di oggetti JSON. Questi verranno mostrati sotto forma di card sulla pagina

“Monitoring”.

Il front-end include una sotto sezione aggiuntiva, Grafana. Tramite Grafana è possibile

visualizzare i dati sotto forma di grafici dal layout accattivante. L’accesso ai dati avviene

esternamente all’app scritta in Angular, sarà il server stesso di Grafana, ad effettuare

delle query cicliche, direttamente al database MySQL. Quindi Grafana deve essere

sempre in esecuzione, così come server e database.

Nei prossimi capitoli verranno analizzate in dettaglio tutte queste sezioni.

## 4 Client hardware

Come già detto il client hardware è rappresentato da una scheda elettronica per la gestione di

sensori, attuatori, motori… il cui centro di controllo e calcolo si trova sulla dev-board ESP32 che

verrà trattata nei sotto capitoli a seguire.

### 4.1 Schema elettrico

Lo schema elettrico ed il circuito utilizzati per questo progetto sono soltanto a titolo

esemplificativo, difatti è possibile adattare lo schema ed i componenti in funzione del tipo di

macchinario che si vuole decidere di monitorare.

Siccome la maggior parte dei macchinari industriali sono dotati di PLC, con circuito molto più

complessi di quello qui sotto descritto, si può optare anche per una soluzione universale con un

approccio quanto più plug and play possibile. Questa soluzione verrà descritta nell’apposito

capitolo “Conclusioni e sviluppi futuri”.

### 4.1.1 Alimentazione

Figura 4.1: Schematico alimentazione

Il circuito di alimentazione si compone essenzialmente di tre parti, una prima parte di filtro in

ingresso, una seconda per stabilizzare la tensione intorno ai 5v ed una terza per stabilizzare

ulteriormente la tensione intorno ai 3.3v.

La prima parte, come detto, è composta da un filtro in ingresso, in particolare il filtro utilizzato è

un filtro pi-greco. Il nome deriva dalla forma dei componenti utilizzati, come si può vedere di

seguito:

Figura 4.2: Schema filtro pi-greco

In generale, sono presenti due condensatori di filtro ed un’induttanza (nel circuito è stato

utilizzata un’induttanza di modo comune, quindi con elemento induttivo sia sul “lato caldo” dei

12v che sul “lato freddo” dei 0v).

Gli alimentatori switching (alimentatori a commutazione), ovvero i classici alimentatori per

cellulari o altri dispositivi elettronici, come quello utilizzato nel progetto, hanno il vantaggio di

essere molto più compatti e di avere un rendimento migliore di quelli tradizionali a

trasformatore, però possiedono il grande svantaggio di essere caratterizzati da un elevato ripple e

dalla generazione di componenti spurie ad alta frequenza, con l’inconveniente di andare ad

interferire con il funzionamento degli altri componenti elettronici presenti nel circuito.

I condensatori hanno lo scopo di ridurre il ripple, ovvero quel segnale, che a seguito di un

raddrizzamento della corrente (da AC a DC), si sovrappone alla tensione continua di lavoro.

Di seguito un esempio di ripple presente su di un’onda raddrizzata:

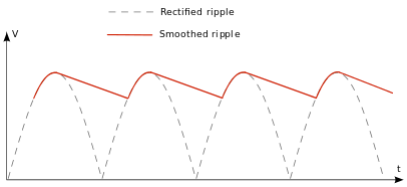
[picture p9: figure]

Figura 4.3: Ripple su onda sinusoidale raddrizzata

Di norma si cerca di attenuare quanto più possibile l’effetto del ripple aggiungendo dei filtri

(condensatori ed induttori in genere), ma l’effetto del ripple è impossibile e costoso da eliminare

del tutto per cui si cerca sempre di adottare la soluzione migliore, al minor costo in funzione

dello scopo del circuito.

In una situazione di questo tipo:

Figura 4.4: Filtro LC passa basso

Condensatore ed induttanza formano quello che è un comune filtro passa basso LC (L =

induttanza, C = condensatore), in grado appunto di eliminare, o meglio tagliare, tutte le

frequenze definite “alte”, ovvero al di sopra della frequenza di taglio del filtro. Questo filtro se

posto in serie ad una fonte di alimentazione in corrente continua (quindi a frequenza ideale 0),

andrebbe ad attenuare le frequenze variabili/alternate sovrapposte alla corrente continua,

generate appunto dall’alimentatore switching.

Nel caso del circuito utilizzato nel progetto, il filtro a pi-greco è ancora più efficace di quello LC,

dato che usa per L1 (vedi figura 4.1) una bobina compensata (detta anche bobina di modo comune), che è formata da 2 avvolgimenti in controfase, avvolti sullo stesso nucleo. In una

bobina come questa, i disturbi presenti in uno degli avvolgimenti generano un flusso magnetico

che crea una tensione identica sull'altro avvolgimento. Il risultato è che se sul “lato caldo” un

disturbo fa aumentare per un istante la tensione, ad esempio, di 1V, anche il “lato freddo” avrà lo

stesso aumento, quindi all'uscita della bobina la tensione presente sarà identica su entrambi i

poli.

In un circuito pi-greco, inoltre, il carico (parte di circuito a valle del filtro) è disaccoppiato dalla

rete elettrica, dall’induttanza, questo aiuta ulteriormente la funzione di filtro.

La seconda parte, si compone di un regolatore di tensione lineare, in grado di abbassare e

stabilizzare la tensione ad un valore di circa 5v:

Figura 4.5: Schematico regolatore 5v

Lo schema prevede quanto riportato nel datasheet [b] e si compone di due condensatori di filtro

per tenere stabile la tensione, in ingresso ed in uscita. Nello schema ne sono stati previsti altri, in

caso dovessero servire. Alla fine è stato aggiunto un diodo led il quale segnala la presenza di

tensione sul ramo dei 5v.

Allo stesso modo è stato progettata la terza parte, per abbassare la tensione dai 5v ai 3.3v,

sempre con condensatori di filtro e led, con circuito basato sul relativo datasheet [c]:

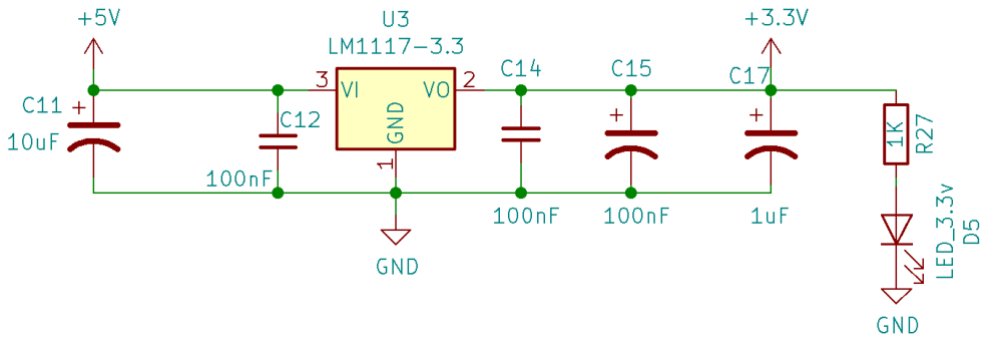
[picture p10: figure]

Figura 4.6: Schematico regolatore 3.3v

### 4.1.2 Controllo led

Nel circuito è stata aggiunta anche una parte di controllo led, sono i led presenti in ogni

postazione i quali segnalano se la macchina è in lavorazione (led verde) o in errore (led rosso).

Questi sono presenti in quasi tutti i macchinari industriali, per il progetto si è pensato di

introdurli in questo modo:

Figura 4.7: Schematico controllo led

Il microcontrollore genera un segnale sulla pista GPIO27 (è presente un GPIO diverso per ogni

led), tramite la resistenza R1 si limita la corrente uscente dal microcontrollore, tramite il

condensatore C4 si cerca di livellare la tensione in modo da evitare il problema del “rimbalzo” di

tensione, la resistenza R2 è la resistenza di pull-down, la quale in assenza di segnali sulla linea

GPIO27 fornisce un livello di tensione a Q1 basso (0v). Infine il transistor NPN BC817

(datasheet [d]) disaccoppia l’uscita del microcontrollore dal led, evitando così di danneggiarlo, a

seguito di assorbimenti di corrente troppo elevati.

R5 invece limita la corrente assorbita dal led secondo la legge di ohm R=V/I.

### 4.1.3 Gestione pulsanti START/RESET

Nella postazione dell’operatore sono presenti due pulsanti, rispettivamente:

- START: per far partire il ciclo di produzione, dopo che l’operatore ha inserito il pezzo

grezzo

- RESET: a seguito di un allarme, l’operatore interviene manualmente e sistema il

problema. Per far ripartire il ciclo deve premere il pulsante di reset.

Figura 4.8: Schematico gestione pulsanti

GPIO22 rappresenta un ingresso del microcontrollore. Il sistema di rilevazione del pulsante

premuto si basa sul portare a GND l’ingresso del microcontrollore. In condizioni di pulsante non

premuto, il microcontrollore leggerà uno stato alto, determinato dalla linea 3.3v collegata alla

linea GPIO tramite le resistenze R6 (resistenza di pull-up) e R3 (resistenza per limitare la

corrente). Nel caso il pulsante venga premuto, la tensione 3.3v non andrà più nella linea GPIO

ma verrà scaricata a massa. Il condensatore C6 funge da anti-rimbalzo.

### 4.1.4 Gestione proximity

In quasi tutti i macchinari industriali sono presenti dei proximity, dei sensori capacitivi in grado

di rilevare la presenza di un corpo metallico a qualche millimetro di distanza, quindi senza

contatto. Si è deciso quindi di prevedere un circuito per l’interconnessione di proximity tra i più

comuni in commercio, quelli a tre fili.

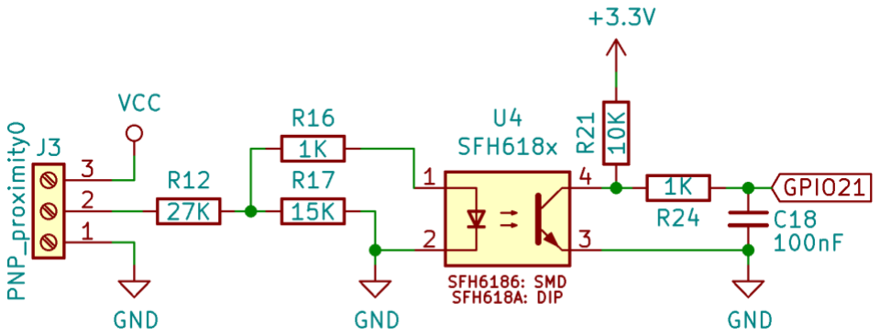
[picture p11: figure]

Figura 4.9: Schematico lettura proximity

Il circuito si compone di un partitore iniziale, formato dalle resistenze R12 e R17, per abbassare

la tensione dai 12v forniti dal proximity ai circa 5v, più accettabili per il foto-accoppiatore. Il

foto-accoppiatore SFH6186 (datasheet [e]) è un componente che serve per disaccoppiare

fisicamente ed elettricamente due parti di circuito con tensioni diverse. Se il proximity rileva il

pezzo, la tensione passerà attraverso il partitore, il quale, la abbasserà a 5v ed alimenterà i piedini

1 e 2 di U4, a cui è collegato internamente un diodo led. Il led illuminandosi attiva il foto-

transistor di U4 il quale entra in conduzione e porta la pista GPIO21, del microcontrollore, a

GND. In condizioni di “pezzo non rilevato” la pista GPIO21 resterà alta (a 3.3v). Con il foto-

accoppiatore si protegge la parte di circuito collegata al microcontrollore evitando che vi possano

entrare tensioni che lo brucerebbero.

### 4.2 ESP32

La scheda utilizzata per il controllo dell’hardware è una dev-board ESP32, la quale monta un

microcontrollore ESP32, prodotto dalla Espressif, dotato di un modulo per la connettività

Bluetooth e WiFi. Con una serie di piedini (il numero varia di versione in versione ma la

funzionalità non cambia), tra i quali vi sono i GPIO che permettono di interagire col

microcontrollore stesso. Fornisce supporto per diverse interfacce tra cui SD card, UART, SPI,

SDIO, I2C, LED PWM, Motor PWM, I2S, IR, pulse counter, capacitive touch sensor, ADC,

DAC, tutti elencati qui sotto:

Figura 4.10: Dev. Board pinout ESP32

### 4.2.1 Principali caratteristiche

CPU e memoria

- Xtensa® single-/dual-core 32-bit LX6 microprocessor(s), fino a 600 DMIPS
- 448 kB ROM
- 520 kB SRAM
- 16 kB SRAM in RTC
- memoria Flash 4 MB

Wi-Fi

- Range di frequenza: 2,4 GHz - 2,5 GHz
- 802.11 b/g/n HT40 Wi-Fi transceiver, baseband, stack e LwIP
- Modalità Sniffer / Station / SoftAP e Wi-Fi direct mode
- Velocità massima dati 150 Mbps@11n HT40, 72 Mbps@11n HT20, 54 Mbps@11g e 11

Mbps@11b

- Massima potenza di trasmissione 19,5 dBm@11b, 16,5 dBm@11g, 15,5 dBm@11n
- Sensibilità minima del ricevitore -97 dBm
- Supporta la modalità di protezione: WEP, WPA/WPA2 PSK/Enterprise
- Crittografia con accelerazione hardware: AES / SHA2 / ECC / RSA-4096

Bluetooth

- Conforme alle specifiche Bluetooth v4.2 BR/EDR e BLE
- Ricevitore NZIF con una sensibilità di -97dBm
- Trasmettitore classe 1, classe 2 e classe 3
- Potenza di trasmissione +12dBm
- Ricevitore NZIF con una sensibilità di -97dBm
- Multi-connessioni Bluetooth e BLE

E molte altre caratteristiche possono essere trovate nel sito o nella documentazione tecnica

presente al link [f].

Il linguaggio utilizzato per la programmazione, è un linguaggio simile al C/C++, per l’esattezza

chiamato Wiring e viene utilizzato nell’IDE Arduino per i microcontrollori compatibili.

### 4.3 Firmware

Il firmware lo possiamo suddividere in due macro-blocchi, una prima parte più importante,

legata all’accesso ed alla comunicazione attraverso internet ed una seconda parte meno

importante legata alla gestione del macchinario (quindi sensori, attuatori, motori ecc…).

Nel seguente capitolo verrà trattata soltanto la prima parte legata all’accesso alla rete, in quanto

più significativa per quel che concerne il progetto stesso.

La seconda parte non ha una rilevanza particolare ai fini del progetto ed è stata usata solamente

per la generazione dei dati da visualizzare.

### 4.3.1 Librerie

Per il progetto sono state utilizzate essenzialmente quattro librerie:

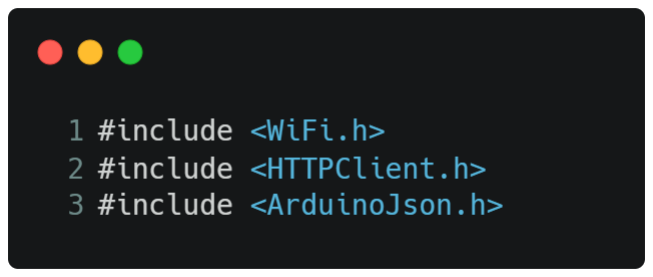
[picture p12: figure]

Figura 4.11: Inclusione librerie

1. WiFi.h: è la libreria che permette al modulo di collegarsi ad internet. Fornisce dei

metodi per il funzionamento sia da server (e quindi accettare connessioni in entrata) che

da client (e quindi fornire connessione in uscita). Effettua la connessione secondo gli

standard WEP e WPA2, utilizzando quindi SSID e password per la connessione alla rete.

2. HTTPClient.h: è la libreria che permette di utilizzare il modulo come un web client

ed espone una serie di funzioni per effettuare delle chiamate GET, POST e PUT ad un

web server, secondo il protocollo HTTP.

3. ArduinoJson.h: è la libreria che permette di raggruppare i dati prodotti, dal modulo,

in un oggetto di tipo JSON. Fornisce diversi metodi interessanti come l’allocazione della

memoria, cast esplicito o implicito, filtri dati… e molti altri che possono essere

approfonditi sul sito [35].

### 4.3.2 Dichiarazione variabili

Figura 4.12: Dichiarazione variabili

Per eseguire il codice è necessario cambiare il valore delle linee 1 e 2 con l’SSID e la password

del proprio wifi. Mentre per il server si dovrà inserire l’indirizzo IP del computer sul quale è in

esecuzione (per l’esecuzione locale del server), o in alternativa l’indirizzo su cui viene hostato

(nel caso si decida di usufruire di un servizio di hosting).

### 4.3.3 Connessione al wifi

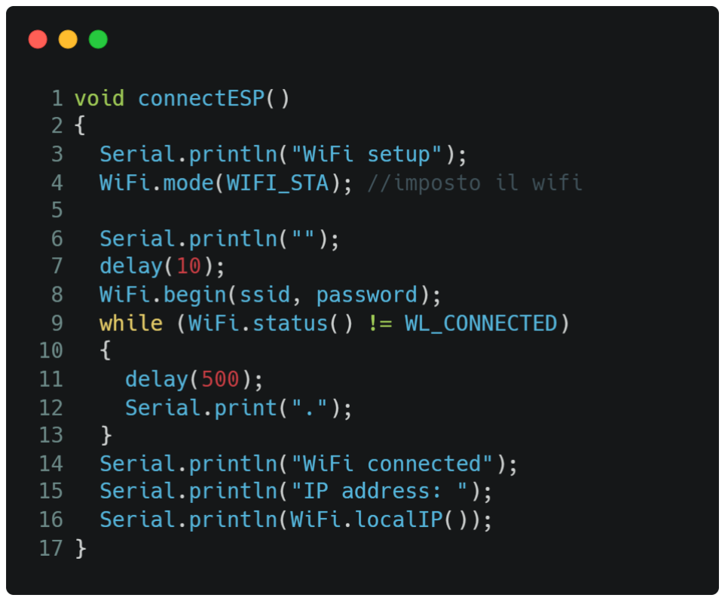
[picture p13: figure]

Figura 4.13: Funzione connessione al wifi

La configurazione della connessione avviene attraverso funzione in Figura 4.13:

Linea 4: viene impostato il tipo di connessione del modulo come stazione (STA). In questo caso

il router fornirà la connessione al modulo e si dovrà collegare ad esso tramite SSID e password

(se richiesta). È possibile però impostare il modulo anche come Access Point (AP), in quel caso

sarà il modulo stesso a fornire connettività ad altri device presenti sulla sua rete.

Linea 8: vengono impostati SSID (Service Set IDentifier) e password per il collegamento alla

rete.

Linee 9-13: tramite la funzione di libreria WiFi.status() si ritorna lo stato della

connessione, connesso o non connesso. Per cui finché il modulo non risulta connesso rimane

dentro al ciclo e controlla lo stato della connessione ogni 500ms.

Linea 16: se tutto è andato a buon fine, il modulo si è connesso e tramite la funzione di libreria

WiFi.localIP(), viene ritornato l’IP assegnato dal router al modulo.

### 4.3.4 Impacchettamento ed invio del messaggio

Figura 4.14: Funzione per gestione ed invio messaggi HTTP

Attraverso questa funzione, vengono passati i dati di produzione, impacchettati in un oggetto di

tipo JSON e inviati al server tramite una POST.

http è un dato di tipo HTTPClient per l’accesso ai metodi della libreria.

Linea 4: tutta l’operazione deve essere svolta verificando ad ogni invio che il modulo ESP sia

connesso.

Linea 7: viene aperta una connessione di tipo HTTP con il server, raggiungibile tramite il

relativo indirizzo presente nelle variabili globali.

Linea 11: alla connessione HTTP vengono aggiunti degli headers (un’intestazione) per

specificare il tipo del contenuto del messaggio (content-type), il quale, in questo caso, è in

formato JSON.

Linea 14: viene creato un JsonDocument per salvare la rappresentazione in memoria

dell’oggetto. In questo caso viene utilizzata l’allocazione statica della memoria, in quanto

l’oggetto è di piccole dimensioni (per le dimensioni dell’oggetto è consigliabile utilizzare il tool

online fornito dal produttore della libreria, ArduinoJson Assistant, accessibile tramite il link [g]).

Linee 14-19: Un JsonDocument vuoto, diventa un oggetto non appena vengono aggiunti dei

“membri” ad esso. Con queste istruzioni vengono aggiunti questi membri, che altro non sono che

i dati da inviare.

Linea 21: tramite il metodo serializeJson(doc, output) viene prodotto un oggetto

JSON (parametro output) a partire da un JsonDocument (parametro doc).

Linea 24: con http.POST(json) viene inviato al server l’oggetto JSON tramite la chiamata

POST. | Questa | fornirà | una | risposta | che | verrà | immagazzinata | all’interno | di

httpResponseCode.

Linea 28: tramite il metodo http.getString() della libreria HTTPClient verrà stampata su

monitor seriale la risposta del server in formato stringa.

## 5 Server NodeJS

Il server rappresenta lo strato back-end del progetto, si è deciso di implementarlo utilizzando

NodeJS.

Il server riveste un ruolo chiave all’interno del progetto, è ciò che sta alla base di tutto, senza il

server il progetto non potrebbe minimamente funzionare a differenza degli altri strati, a cui

invece, il progetto potrebbe anche fare a meno.

Lo scopo del server è quello di gestire le richieste di client e front-end e favorire lo scambio dati

tra questi ed il database. Se si volesse fare un’analogia con una strada, il server sarebbe il vigile

che gestisce tutto il traffico derivante dalle diverse strade (route) e confluenti tutte in un unico

punto (il server per l’appunto).

Si può suddividere, a livello logico, il codice del server in tre parti: una prima parte relativa alla

ricezione dei messaggi da parte dei diversi client hardware, una seconda parte relativa al

salvataggio dei dati nel database ed una terza parte relativa alla richiesta dei dati da parte del

front-end.

### 5.1 Moduli utilizzati

Come già accennato nei capitoli precedenti, Node si compone di diversi moduli. Questi sono

come delle classi in Java, con l’unica eccezione che attraverso il gestore dei moduli NPM, è

possibile accedere ad una miriade di moduli già scritti e testati da milioni di persone (per cui si

presuppone che siano funzionanti e senza bug), per cui sarà sufficiente installarli da riga di

comando con: npm i nome_modulo, il modulo verrà così installato a livello locale nel

progetto e sarà possibile usarlo dopo averlo importato nel progetto, come verrà mostrato in 5.2.1.

### 5.1.1 Express

Express rappresenta il modulo più importante tra tutti quelli utilizzati nel server. È quel modulo

che permette di creare web server con NodeJS, basti pensare che ogni settimana viene scaricato

ed installato circa ventidue milioni di volte nel mondo, questo solo per capire quanto viene

utilizzato a livello globale, tant’è che ormai è stato definito come il framework server “di fatto”

di Node.

Express fornisce una serie di API che consento di gestire le chiamate HTTP provenienti da

diverse route.

### 5.1.2 Sequelize

Sequelize è un modulo meno utilizzato di Express, registra un trend di poco più di un milione di

download settimanali, ma non per questo vuol dire che sia meno valido.

Sequelize è un modulo basato su promise, ovvero oggetti rappresentanti l’eventuale compimento

o fallimento di un’operazione asincrona e del suo risultato. In particolare viene definito ORM

(Object Relational Mapper), ovvero uno strumento che consente l’interazione con il database

senza conoscere di preciso il linguaggio utilizzato dal database (SQL). In parole povere,

Sequelize fornisce un livello di astrazione tra server e database, per cui non si rende necessario

conoscere la sintassi specifica del DBMS utilizzato. Sequelize fornisce supporto a diversi

DBMS, tra cui Postgres, MySQL, MariaDB, SQLite, DB2 e Microsoft SQL. Per accedere ad uno

di questi sarà necessario fornire le credenziali di accesso al DB ed il nome del DBMS utilizzato,

tra quelli citati. Successivamente l’inserimento di righe da parte del server avviene tramite

funzioni javascript, come si vedrà nei prossimi paragrafi.

### 5.2 Codice

Di seguito verranno riportati le parti di codice utili alla comprensione del progetto.

### 5.2.1 Importazione di moduli, middleware e file custom

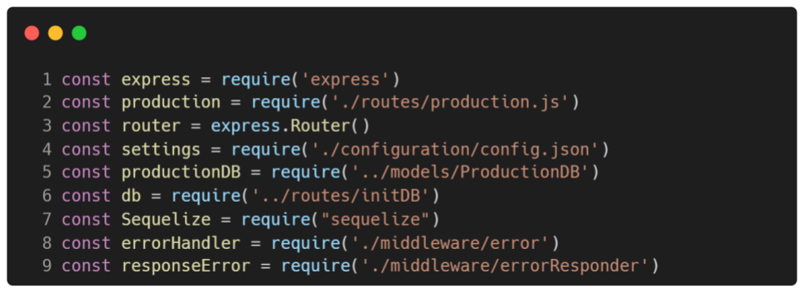
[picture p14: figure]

Figura 5.1: Importazione moduli

Nei diversi file, sono stati importati alcuni moduli, il primo è Express descritto nel capitolo

precedente ed il secondo è un modulo interno, scritto appositamente per l’applicazione, serve per

gestire le chiamate ad una path particolare, in questo modo tutte le chiamate aventi URL che

inizia con localhost:3000/produzione/ saranno gestite all’interno di questo file.

Questo permette di avere un codice più pulito e modulare.

Il terzo è Router, un modulo built-in di express che permette di creare delle parti di percorso

univoche per più route, come fatto per production.js.

Settings invece non è propriamente un modulo, ma è associato ad un file JSON (config.json)

contenente tutti i parametri di configurazione utilizzati nel progetto. In questo modo se si

dovesse cambiare la porta del server od il nome del database, lo si potrebbe fare semplicemente

da quel file, senza dover cercare la costante all’interno di tutto il progetto.

productionDB è un file sempre custom, un modello ed ha lo scopo di definire, per l’appunto, un

modello per la scrittura dei dati sul DB, in sostanza va a definire quali saranno i dati ed il loro

tipo.

Il prossimo si tratta sempre di un modulo custom, che consente di eseguire delle funzioni base

sul DB, come l’autenticazione, test di connessione e sincronizzazione.

Sequelize, come già descritto, permette di accedere al database in modo più semplice attraverso

delle API mascherate da funzioni universali per diversi DB.

Gli ultimi due, sono dei middleware custom, i quali espongono delle funzioni, in particolare

questi middleware servono per la cattura e la gestione degli errori.

La sintassi prevede di associare ad una costante, con require, l’importazione del modulo. Nel

caso si tratti di modulo esterno basta scrivere il nome del modulo stesso, nel caso di modulo

interno si deve indicare il percorso relativo (ovvero partendo dal file in cui il modulo viene

importato).

### 5.2.2 Definizione delle CORS policy

CORS (Cross-Origin Resource Sharing) è un meccanismo basato sugli headers HTTP, che

permettono al server di indicare qualsiasi origine oltre la sua, dal quale il browser dovrebbe

permettere il caricamento di risorse.

Figura 5.2: Definizione ed utilizzo delle CORS policy

Molto brevemente si può vedere che con questa piccola parte di codice si va a definire l’origine

(“*” sta a significare qualsiasi path), i metodi (quindi i classici GET, PUT, POST…) e gli

headers (quindi il tipo di contenuto della richiesta, la lunghezza…).

Se non venissero implementati, Google potrebbe segnalare un errore relativo all’assenza di

questi headers, ad esempio:

Figura 5.3: Errore Google per CORS non implementate

### 5.2.3 Definizione porta del server

Il server per essere messo in esecuzione necessita che gli venga assegnata una porta:

Figura 5.4: Definizione porta server ed inizializzazione

Linea 2: Il server viene messo in ascolto nella porta locale definita nel file config.json.

Linea 4: Nel caso di eccezioni non gestite il server terminerebbe la sua esecuzione, per cui con

questo comando si vanno a catturare tutte le eccezioni non gestite.

### 5.2.4 Definizione route

Per permettere al server di identificare l’origine della risorsa, è possibile creare delle route di

navigazione, per cui, in funzione dell’URL a cui viene fatta la richiesta, il server gestirà quella

richiesta secondo delle determinate funzioni.

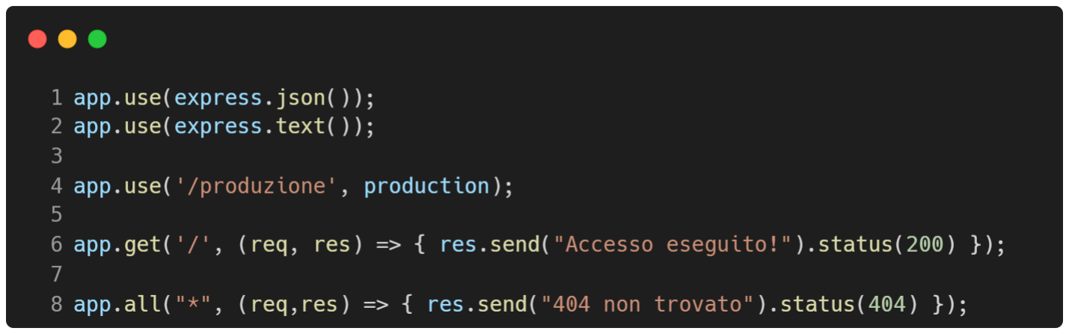
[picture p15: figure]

Figura 5.5: Definizione delle route del progetto

Questo è un primo esempio di utilizzo delle route di express.

Linee 1-2: utilizzo di middleware di express per permettere la lettura di testi e JSON in arrivo

dalle varie richieste.

Linea 4: nel caso di più percorsi con la stessa parte iniziale di URL è possibile definire un

modulo interno che li gestisca tutti (ad esempio “localhost:3000/produzione/inserisci” e

“localhost:3000/produzione/rimuovi” e “localhost:3000/produzione/modifica”, tutti hanno lo

stesso prefisso).

Linea 6: con questa API si gestisce una GET con path localhost:3000/. Collegandosi al

browser con questa URL automaticamente viene effettuata una GET, il server istanzierà una

funzione di callback ricevente i parametri req (request, ovvero la richiesta) e res (response,

ovvero la risposta del server) la quale risponderà al client con la stringa “Accesso eseguito”.

Linea 8: può succedere che venga digitata un’URL non gestita e non esistente nel progetto, tale

per cui Google segnalerebbe un errore. Per evitare ciò è bene gestire le richieste a tutte le URL

non gestite andando a definire una funzione che le racchiuda tutte. Con “*” si identificano tutte

le route, deve essere posto alla fine delle definizioni delle route, in questo modo verrà eseguita

per ultima ed andrà a catturare soltanto le route non gestite, restituendo un messaggio di errore

con il relativo status code.

### 5.2.5 Ricezione dati da client hardware

La ricezione dei dati dal client hardware, avviene attraverso una POST, il client effettua una post

al server ed il server la intercetta.

Figura 5.6: Route per ricezione dati da client hardware

Linea 1: viene dichiarata una variabile array “dati” per immagazzinare i dati ricevuti dal client

hardware.

Linee 4-20: tramite l’API POST all’URL localhost:3000/produzione/inserisci viene inserito il

corpo della richiesta nella variabile “dati”.

Linee 6-7: variabili per contenere e scorporare la richiesta ricevuta dal client hardware.

Linee 10-12: tramite un foreach viene iterato l’array dati per cercare se nei dati ricevuti è

presente o meno un oggetto con lo stesso idMachinery, in tal caso salva l’indice nella variabile

“i”.

Linee 14-15: se nella ricerca precedente è stato trovato un elemento con idMachinery uguale a

quello della request, allora sostituisce l’elemento i-esimo dell’array “dati” con quello ricevuto.

Linee 23-26: con la funzione, vengono inseriti i dati ricevuti nel database, creando una nuova

riga (funzione del modulo sequelize). Questa funzione di sequelize aggiunge automaticamente

due colonne alla tabella: createdAt(indica data e ora di creazione della riga) e

updatedAt(indica data e ora di modifica della riga, se non modificata, data e ora di creazione).

### 5.2.6 Configurazione DB

La configurazione del database si compone di più parti:

- Creazione di un’istanza del modulo sequelize

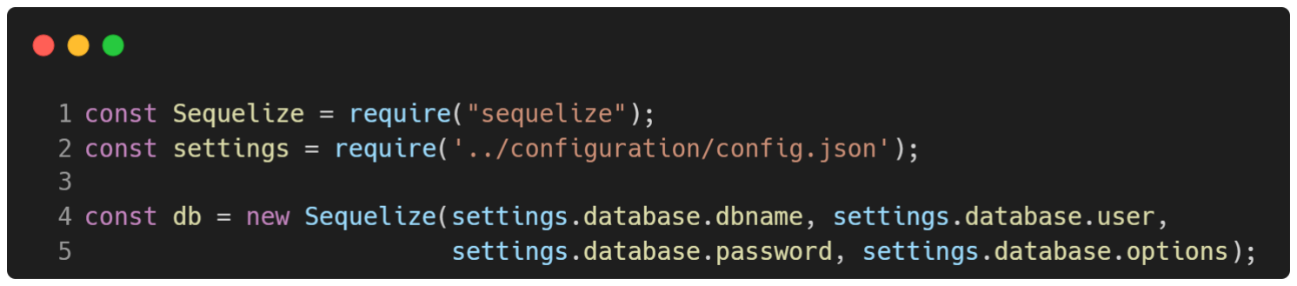
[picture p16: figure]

Figura 5.7: Inizializzazione DB con Sequelize

In questa parte, viene creata un’istanza del modulo sequelize e vengono impostati una serie di

parametri che vanno a definire l’host per la connessione al DB, il DBMS utilizzato (mysql) ed

altri parametri propri di MySQL, tutti riportati sul file di configurazione config.js.

Da qui in poi, l’accesso al database avverrà tramite l’istanza “db”.

- Test connessione

Figura 5.8: Test connessione/autenticazione DB

Dopo aver istanziato db, è bene effettuare un test della connessione, per verificare che tutto sia

andato a buon fine, per cui tramite il metodo authenticate() di sequelize viene restituita

un’eccezione nel caso di connessione fallita, mentre se tutto è andato a buon fine, viene stampata

la stringa “database connected”.

- Sincronizzazione al database

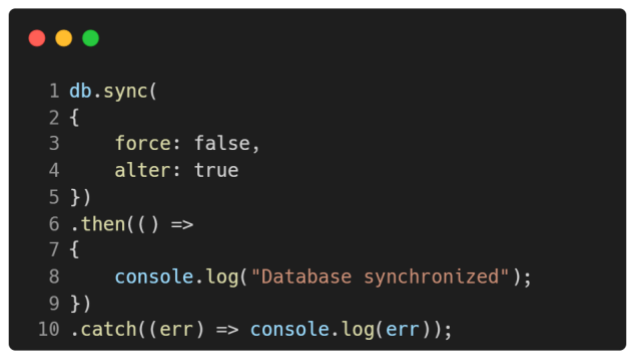
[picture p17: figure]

Figura 5.9: Sincronizzazione DB

Se il test di connessione è andato a buon fine, ora sarà possibile accedere al DB con i metodi

propri del modulo sequelize.

Nel caso si debba accedere alle tabelle del database in sola lettura, il problema di

sincronizzazione non si pone. Ma nel caso si debba accedere anche in scrittura (come nel

progetto), si dovrà effettuare una sincronizzazione tra quanto gli viene passato e quanto

effettivamente è presente sul database.

Il metodo sync() di sequelize permette di fare ciò.

Linea 3: con il parametro force impostato su false, si va a indicare a sequelize che nel caso la

tabella, su cui andiamo a scrivere, esiste già, non ne ricrea una nuova.

Linea 4: con alter impostato a true, si dà a sequelize la facoltà di modificare la tabella

esistente sul database per farla corrispondere ai dati che gli vengono inviati. Ad esempio, se nella

tabella del DB sono presenti due colonne, nome e cognome, e da Node si cerca di inserire nome,

cognome ed indirizzo, automaticamente sequelize aggiungerà una colonna per l’indirizzo. Tutte

le righe prima di quella appena inserita avranno parametro indirizzo impostato a null.

Anche in questo caso viene restituita un’eccezione nel caso di sincronizzazione fallita, mentre se

tutto è andato a buon fine, viene stampata la stringa “Database synchronized”.

### 5.2.7 Modello dati

Il modello dei dati, rappresenta la struttura e tipologia dei dati che il server dovrà ricevere.

Normalmente può anche essere evitata questa parte, il server funzionerebbe lo stesso, basterebbe

soltanto definire la tipologia di dato in ricezione come any, ovvero qualsiasi dato. Il problema

più grosso di questo approccio è che qualsiasi dato potrebbe essere inviato al server, anche dati

infetti, che potrebbero creare una breccia nel server e permettere l’accesso a malintenzionati.

Per questo motivo, è sempre buona norma, definire un modello dati in ingresso, così che, se un

tipo di dato non dovesse corrispondere, l’accesso al server verrebbe bloccato.

Questa soluzione però oltre a comportare una buona prassi in fatto di sicurezza, limita la

scalabilità dell’applicazione, in quanto se un giorno si dovesse decidere di inviare un parametro

aggiuntivo, oltre ad aggiornare il client hardware, si dovrebbe aggiornare anche il server (il

database non necessita di modifiche in quanto si occupa di tutto il modulo sequelize).

Di seguito viene rappresentato il modello dati utilizzato nel progetto, dove è possibile notare la

presenza di sei parametri, ovvero id, idMachinery, idProduct, position, status ed errorCode,

ognuno dei quali rappresenta un dato fondamentale per conoscere la posizione del pezzo in

lavorazione ed il suo stato.

Siccome alcuni di questi dati permettono assieme di identificare univocamente un pezzo

all’interno del ciclo produttivo, sono stati impostati come obbligatori (allowNull: false).

Nella figura 5.10 la loro rappresentazione a livello di codice:

Figura 5.10 Modello dati del progetto

## 6 Database MySQL

Per il salvataggio dei dati si è deciso di utilizzare come database MySQL, uno dei database

relazionali più conosciuti ed utilizzati.

MySQL è accessibile sia da riga di comando che tramite interfaccia grafica (chiamata

Workbench), possono essere utilizzati entrambi, ma per i successivi sotto-capitoli verrà utilizzato

il Workbench per mostrare la tabella creata e riempita durante i test mentre la riga di comando

per la procedura di creazione del database.

### 6.1 Creazione nuovo utente

La procedura per la creazione dell’utente è una fase che non rientra nel codice del progetto ma è

una parte fondamentale per l’esecuzione dello stesso. Questa fase la si può inquadrare in una fase

preliminare.

Innanzitutto è necessario installare MySQL sul proprio computer, in Windows ci si può avvalere

del mysql installer per Windows, scaricabile dal sito visitabile al link [h].

Scaricato questo si segue tutta la procedura di installazione, al termine verrà mandato in

esecuzione il workbench, il quale apparirà come segue:

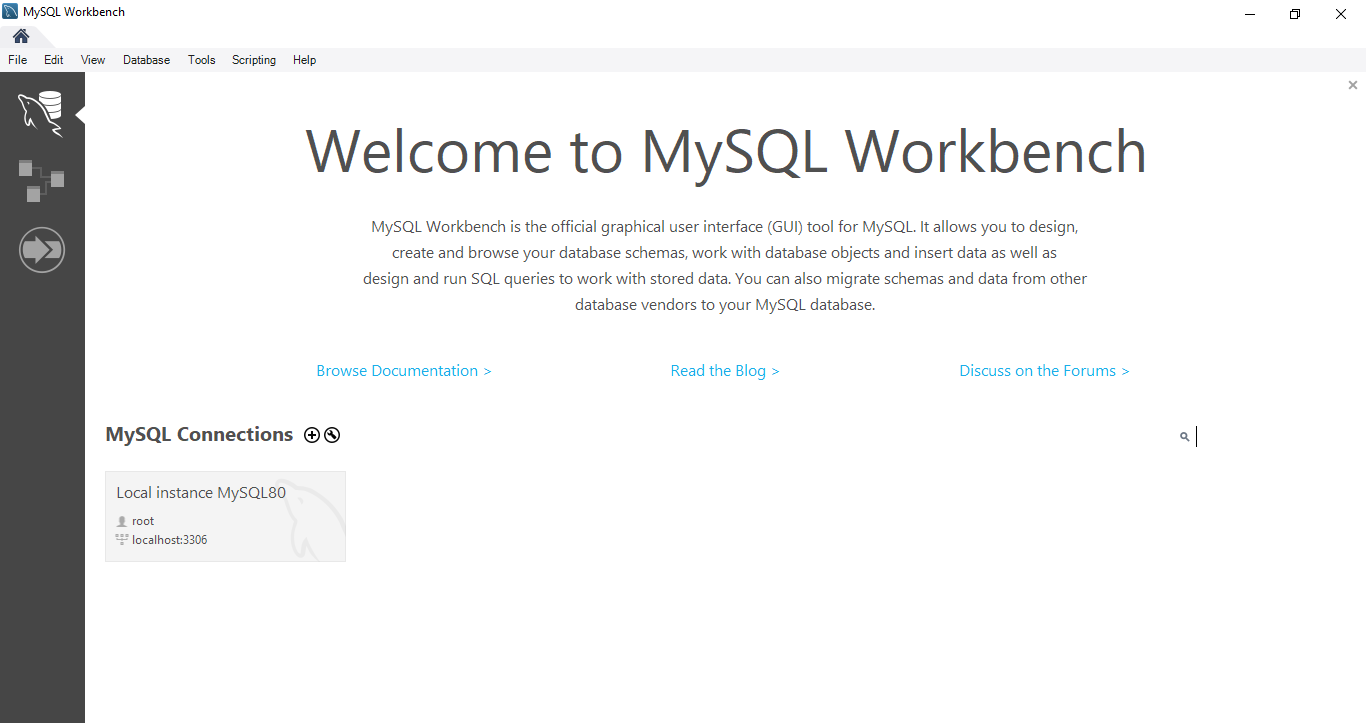
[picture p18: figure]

Figura 6.1: Schermata MySQL Workbench, con utente root

Se non espressamente voluto in fase di installazione, l’unico utente presente sarà l’utente root,

ovvero l’utente “amministratore”, con tutti i privilegi. Solitamente è bene creare un utente nuovo

per l’accesso al database, al quale verranno forniti soltanto i privilegi necessari per il compito

che deve svolgere.

La procedura migliore e più veloce per la creazione di un nuovo utente è tramite linea di

comando.

Aprire il CMD (Command line) e digitare il comando mysql per entrare nella modalità di

scrittura di codice SQL.

Possono presentarsi degli errori, i più comuni sono:

Figura 6.2: Errore variabile d'ambiente non impostata

Questo avviene nel caso non siano state impostate le variabili d’ambiente Windows, per cui è

necessario impostarle.

Oppure un altro errore comune potrebbe essere questo:

Figura 6.3: Errore servizio non attivo

Questo è dovuto al fatto che il servizio MySQL non è in esecuzione, per cui bisogna accedere ai

servizi Windows, trovare il servizio, che di norma viene chiamato MySQL80, ed avviarlo:

Figura 6.4: Attivazione servizio

Una volta fatto questo digitando mysql -u root -p ed inserendo la password impostata

durante la fase di installazione sarà possibile accedere in modalità SQL all’utente root:

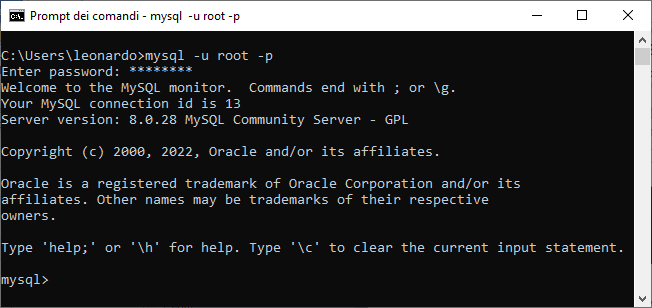
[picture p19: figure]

Figura 6.5: Accesso a MySQL da CMD

Ora sarà possibile digitare il codice SQL che si vuole, in questo caso si dovrà creare un nuovo

utente nel seguente modo:

Figura 6.6: Creazione nuovo utente

Dove “leo” è l’username del nuovo utente, localhost è l’indirizzo della connessione del

database, in questo caso in locale sul pc. Infine “mia_pss” è la password per accedere

all’utente appena creato.

Successivamente è necessario impostare i privilegi necessari per l’utente creato, quindi:

Figura 6.7: Assegnazione privilegi al nuovo utente

In questo caso sono stati garantiti tutti i privilegi necessari per questo utente (ALL

PRIVILEGES) a tutte le tabelle presenti in tutti i database (*.*).

È possibile anche garantire l’accesso soltanto ad alcune determinate azioni, digitando:

- ALL PRIVILEGES: consente l'accesso completo al database (o meglio, all’intero

MySQL Server);

- CREATE: consente all’utente di creare nuovi database e tabelle;
- DROP: consente all’utente di cancellare database e tabelle;
- DELETE: consente all’utente di cancellare record dalle tabelle;
- INSERT: consente all’utente di inserire record nelle tabelle;
- SELECT: consente all’utente di interrogare i database per leggerne il contenuto;
- UPDATE: consente all’utente di modificare i record presenti nelle tabelle;
- GRANT OPTION: consente all’utente di aggiungere o rimuovere privilegi ad altri utenti.

Ed impostare il database e la tabella specifica a cui concedere tali privilegi digitando

nomeDatabase.nomeTabella al posto di *.* .

Terminata questa operazione, bisogna effettuare un aggiornamento interno dei privilegi. Lo si

può effettuare mediante il seguente comando:

Figura 6.8: Aggiornamento privilegi

Fatto questo l’utente sarà creato e potrà essere effettuato l’accesso digitando come prima i

comandi di accesso, dopo essere usciti dalla modalità SQL:

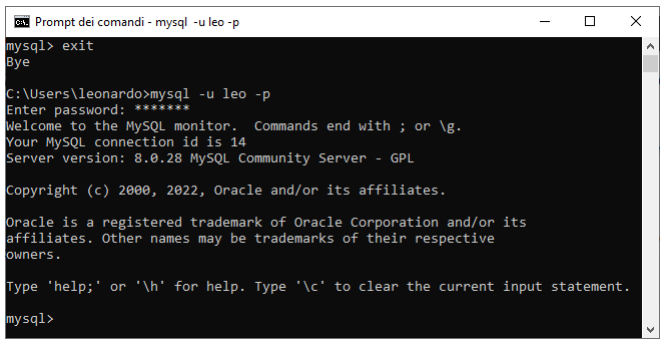
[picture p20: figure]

Figura 6.9: Autenticazione con nuovo utente

### 6.2 Creazione database

Terminata la procedura per la creazione del nuovo utente, è necessario creare il database

all’interno del quale il modulo sequelize di NodeJS andrà a creare la tabella per i dati ricevuti ed

ad inserirveli.

La procedura è molto semplice e come prima è possibile utilizzare la linea di comando:

Figura 6.10: Creazione database

Fatto questo il database è pronto per ricevere i dati dal server. È bene ricordare che, affinché

tutto funzioni, il servizio di MySQL deve essere attivo sempre, come d’altronde il server

NodeJS, cosicché i dati possano sempre essere memorizzati quando un client hardware ci si

connetterà.

Tutte le query, sono comunque disponibili per la consultazione nel repository gitHub.

### 6.3 Opzionale – visualizzazione su Workbench

Nel caso non si volesse utilizzare la linea di comando per visualizzare le tabelle ma si volesse

utilizzare il Workbench di MySQL allora bisogna aggiungere una connessione a quelle esistenti.

Questo è possibile farlo aprendo il Workbench e cliccando la “+” nella sezione “MySQL

Connections”:

Figura 6.11: Creazione di una nuova connessione

Figura 6.12: Parametri nuova connessione

Si dovrà inserire il nome della connessione, l’hostname (che di default è 127.0.0.1, ovvero il

localhost) e l’username dell’utente creato in precedenza. Cliccando su “Test Connection” verrà

effettuato un test sulla connessione, verrà chiesta la password e se tutto andrà a buon fine verrà

visualizzato il seguente messaggio:

Figura 6.13: Finestra connessione correttamente creata

Dopodiché la connessione sarà disponibile nel Workbench e per accedere sarà sufficiente

cliccarci sopra ed inserire la password. All’interno si avrà la possibilità di scrivere del codice

SQL ed eseguirlo per visualizzare/modificare/creare dati in linea con i privilegi concessi

all’utente in uso.

Figura 6.14: Elenco connessioni disponibili

## 7 Front-end Angular

Il front-end generalmente è l’ultimo livello di un’applicazione, ovvero quel livello che permette

di mostrare i dati all’utente sotto forma di grafici, tabelle od in generale utilizzando funzioni

grafiche.

Per questo progetto si è deciso di utilizzare il framework Angular sviluppato da Google, in

quanto nello scenario applicativo è molto richiesto dal mondo del lavoro.

Esso, come già detto, permette di creare applicazioni mono-pagina, il cui contenuto viene

caricato sul browser tutto insieme, durante l’accesso al sito, e modificato dinamicamente durante

l’esecuzione.

Angular implementa una strutturazione interna, a componenti. Questa particolarità lo rende

modulare al massimo e si avvicina molto ai concetti di programmazione ad oggetti studiati nel

corso di Ingegneria del software.

### 7.1 Componenti applicazione

L’applicazione del progetto si compone di diversi moduli, in Angular chiamati componenti i

quali svolgono ognuno una determinata funzione:

Figura 7.1: Struttura dell’app

Ogni componente si compone di quattro file, come spiegato nel capitolo 2.5.

Nei seguenti sotto-capitoli verranno trattati tutti i componenti presenti, dando maggiore enfasi al

file Component.ts e Components.html, ovvero quelli che contiengono le principali funzioni

javascript/typescript.

Il resto dei file invece, viene lasciata al lettore la possibilità di visionarli sul repository GitHub.

Struttura dei componenti

Figura 7.2 Struttura componenti Angular

### 7.1.1 AppComponent

È il componente principale, questo viene generato in automatico da Angular durante la creazione

di un nuovo progetto.

In questo modulo è stata definita la toolbar ed il menù del sito, i quali contengono

rispettivamente, logo e nome dell’app ed i bottoni per navigare nelle altre sezioni del sito.

### 7.1.2 Menu

Questo componente rappresenta un componente inserito direttamente nell’AppComponent e

quindi presente in ogni schermata.

Si compone essenzialmente di tre bottoni e tramite questi è possibile selezionare quale tra gli

altri tre componenti principali (Home, Monitoring e Historical) visualizzare.

La cosa interessante presente in questo componente è la presenza del routerLink, ovvero una

direttiva propria di Angular, che permette di navigare tra i componenti del progetto:

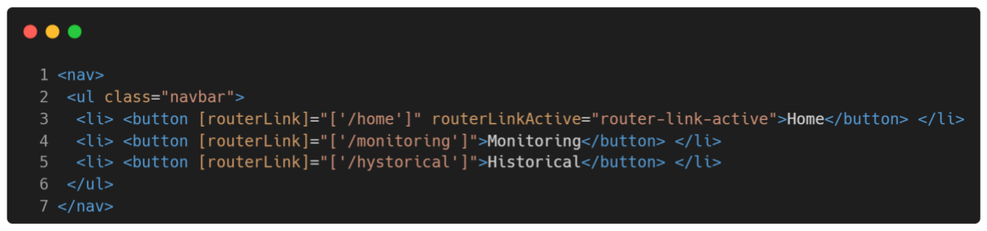
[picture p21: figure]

Figura 7.3: Esempio utilizzo routerLink

Basterà indicare la route presente nel file app-routing.module.ts ed Angular mostrerà il

componente ad essa associato.

### 7.1.3 Home

È il componente che consente la visualizzazione della home, ovvero la pagina che appare

all’apertura del sito.

La funzione principale di questo componente è la visualizzazione delle immagini dei macchinari.

Tramite un selettore è possibile scegliere un macchinario tra quelli che stanno trasmettendo dati

al server.

Passando il mouse sopra i pallini, sarà possibile visualizzare una breve descrizione della

postazione di lavorazione in cui il pallino è posto.

Questa parte è stata fatta implementando l’immagine del macchinario in formato SVG

(ScalableVectorGraphics) ed andando a rendere reattiva (responsive) l’immagine direttamente

inserendo del codice all’interno dell’immagine SVG. Questa operazione è stata svolta con

Inkscape, un software di disegno vettoriale che permette di aggiungere semplice codice XML

alle immagini (come un mouseover, mouseleave…), direttamente da un pannello di

configurazione e quindi definire il colore, piuttosto che l’opacità dell’immagine o il testo da

mostrare.

Di seguito viene rappresentato il pannello “proprietà oggetto” all’interno della quale è stato

possibile inserire le funzionalità sopra descritte.

Figura 7.4: Schermata proprietà oggetto Inkscape

Risultano particolarmente interessanti, due funzioni utilizzate nel codice HTML, attraverso le

quali è possibile, grazie ad Angular, definire dei blocchi condizionali. Di cui si riporta un

esempio non tratto dal codice utilizzato per il progetto:

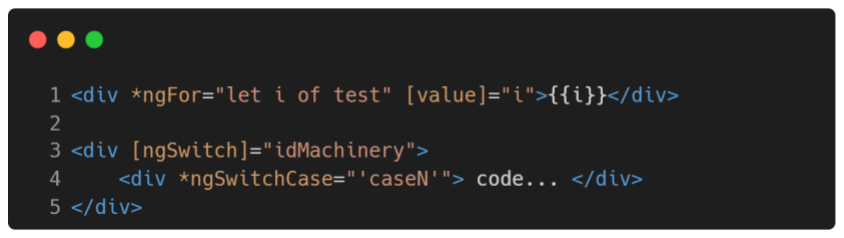
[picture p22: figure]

Figura 7.5: Esempio di utilizzo di blocchi condizionali in HTML

Grazie ad Angular è infatti possibile poter inserire dei blocchi condizionali, come If/Else, For,

Switch. Rendendo di fatto il linguaggio HTML un linguaggio dinamico ed ampliando così le

possibilità di rendere il codice più modulare

### 7.1.4 Monitoring

È il componente principale, quello che permette di monitorare lo stato di produzione di ogni

macchinario in tempo quasi reale.

Nel template di questo componente è possibile visualizzare tutti i dati di produzione inviati da

ogni client hardware, sotto forma di schede. Le schede rappresentano un altro componente

integrato in Monitoring.

È possibile selezionare solo uno dei macchinari presenti, attraverso un apposito form posto in

alto a sinistra e visualizzare i dati in cambiamento solo di quel macchinario.

Il form presenta il meccanismo del databinding, tale per cui è possibile passare dati dal template

HTML al file di gestione monitoring.component.ts.

Figura 7.6: Esempio utilizzo del databinding (ngModel)

Il meccanismo del databinding è fornito proprio da ngModel, il quale permette di accedere ad

una variabile presente nel file monitoring.component.ts e modificarla (in questo caso inserire il

valore immesso dall’utente).

L’altra particolarità fornita sempre da Angular è la possibilità di accedere ad una funzione

(nell’immagine, selectMachinery(…) ), al verificarsi di un evento, come ad esempio il click sul

pulsante.

La funzione più importante svolta all’interno del componente è quella di richiesta dei dati.

I dati vengono richiesti al server tramite l’apposito servizio, che verrà descritto nei capitoli

successivi, nel componente però è stata eseguita una sottoscrizione al servizio, tale per cui ogni

volta che i dati, nel servizio, cambieranno, questa modifica sarà notificata a tutti gli iscritti (in

gergo subscriber). Come un meccanismo di newsletter, dove un elemento centrale, notifica agli

iscritti eventuali novità (news).

Di seguito viene riportata la funzione di sottoscrizione al servizio, la quale avviene all’avvio del

componente (ngOnInit) e viene disiscritta soltanto alla distruzione del componente

(ngOnDestroy).

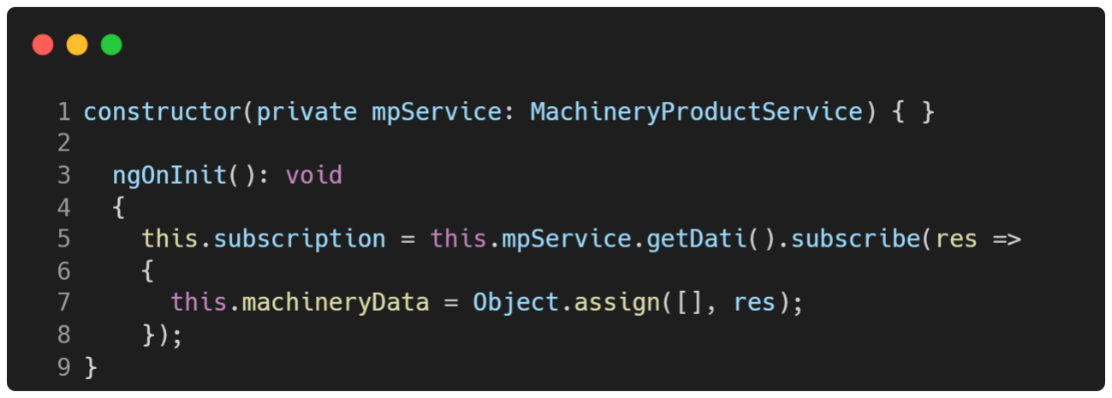
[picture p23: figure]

Figura 7.7: Esempio sottoscrizione ad un servizio

Linea 3: tramite il costruttore si importa il servizio.

Linea 5: si accede al servizio e si effettua una sottoscrizione al metodo getDati, per cui ogni

volta che questo metodo effettuerà una notifica, questa verrà catturata e posta all’interno della

variabile subscription di tipo Subscription (questo serve per effettuare, successivamente, una

disiscrizione).

Linea 7: il contenuto di res viene copiato in machineryData, tramite il metodo Object.assign(),

in quanto l’operatore “=” in Javascript ha una funzione particolare ed assegnerebbe ad entrambe

le variabili il contenuto di machineryData

### 7.1.5 Card

Questo rappresenta un sotto-componente di Monitoring e presenta una serie di parametri che

consentono al componente padre di mostrare i dati all’utente.

Si è scelto questo approccio perché più modulare e scalabile, non è possibile sapere in anticipo

quanti macchinari staranno trasmettendo in un certo istante di tempo. Per cui, in linea con la

programmazione orientata agli oggetti, si è deciso di separare questo componente e renderlo a sé

stante, in questo modo tramite un semplice ciclo for sarà possibile stampare quante card saranno

necessarie in modo del tutto automatico.

Anche in questo caso si è utilizzato il concetto del databinding passando l’array di macchinari

dal componente padre (Monitoring) al componente figlio (Card).

Con il costrutto ngFor è possibile iterare anche su di un componente, passandogli ad ogni ciclo

dei dati diversi:

Figura 7.8: Esempio utilizzo di ngFor per iterare su un componente

I dati vengono immessi nel componente Card attraverso il databinding, quindi nel componente

che riceve i dati è necessario specificare la variabile che si occuperà di ricevere quei dati. Per

fare questo in Angular si deve utilizzare il decoratore @Input():

Figura 7.9: Esempio utilizzo decoratore Input per databinding

### 7.1.6 Historical

Questo è l’ultimo dei componenti e permette di visualizzare i grafici relativi allo storico di

produzione. Non presenta nessuna funzione o nessun costrutto in quanto viene utilizzato come

contenitore per i grafici importati da Grafana.

### 7.2 Grafana

Per la sezione relativa allo storico, si è deciso di utilizzare Grafana in quanto permette di

accedere direttamente al database, quindi non c’è la necessità lato front-end di gestire i dati da

visualizzare.

L’accesso al database avviene effettuando delle query in linguaggio SQL (per quanto riguarda

l’utilizzo di Grafana con MySQL), andando a selezionare le tuple che servono per il grafico.

Esistono due tipologie di grafico che si possono creare, il primo è su base temporale (time

based), ovvero, è possibile selezionare i dati di interesse per l’asse y, mentre sull’asse delle x

sarà necessario selezionare una colonna che presenta un dato in formato DATE_TIME, DATE o

TIME (o mascherarlo come tale).

La seconda tipologia di grafico (table), non prevede la presenza obbligatoria di dati “temporali”

in quanto i dati stessi vengono rappresentati sotto forma di tabella, come se fosse il risultato di

una query classica al database, in questo però non abbiamo nessun riferimento al tempo. Il

formato table permette inoltre la visualizzazione con istogrammi, grafici a torta e molti altri

ancora.

Nel progetto sono state utilizzate entrambe le tipologie di grafico. In particolare, in relazione al

grafico basato sul tempo, come si può notare nel progetto non esiste nessuna riga di codice

relativa alla memorizzazione temporale in quanto, grazie a sequelize, nel database per ogni riga

sarà presente una colonna relativa a data e ora di creazione della riga stessa ed una relativa a data

e ora di modifica della stessa (coincidente con quella di creazione se non sono avvenute

modifiche).

Siccome uno stabilimento produttivo si può comporre di più macchinari connessi, si è deciso di

implementare nello storico, la possibilità di visualizzare un solo macchinario o più macchinari o

tutti, attraverso l’utilizzo delle “Variables” di Grafana. Ottenendo un risultato come il seguente:

Figura 7.10 Funzione di selezione del macchinario

Nei prossimi sotto-capitoli verranno mostrate le diverse tipologie di grafico utilizzate.

### 7.2.1 Grafico PASS/FAIL di ogni postazione

Nel grafico in oggetto, sono presenti delle rappresentazioni simili a tachimetri (meglio definiti

gauge):

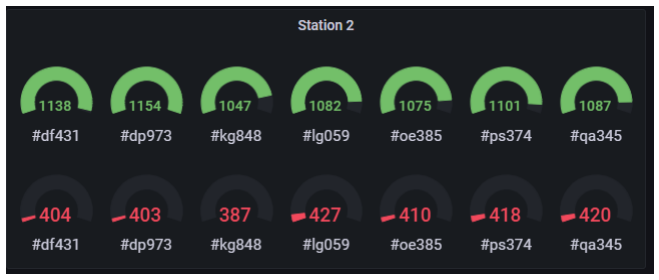
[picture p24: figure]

Figura 7.11 Grafici PASS/FAIL per la stazione 2

Per ogni id-prodotto è possibile visualizzare il numero dei “PASS” (in verde nella riga in alto) ed

i “FAIL” (in rosso nella riga in basso). Il tutto in relazione al macchinario selezionato, per ogni

codice prodotto (#df431, #dp973…).

Questo è stato scelto perché molto spesso, nelle aziende, non si tiene uno storico dei pezzi

prodotti buoni e degli scarti ottenuti per ogni postazione, ma soltanto uno storico in funzione del

prodotto finito. Questa è una cattiva gestione della produzione in quanto grazie ad un sistema

come quello sopra descritto è possibile intervenire preventivamente sulle postazioni che

generano più scarti, diminuendo così gli scarti e di conseguenza aumentando la produzione.

### 7.2.2 Grafico temporale

Un’altra funzionalità importante è quella di tenere traccia giornalmente o settimanalmente, dei

pezzi prodotti.

Figura 7.12 Grafico temporale di pezzi prodotti

Non è nulla di nuovo in quanto ogni azienda mette in atto un sistema di controllo della

produzione giornaliera. Però la cosa interessante adottata nel grafico sopra presente è la

possibilità di visionare, quasi in tempo reale, la produzione odierna. Analizzando soprattutto

come varia la produzione nelle diverse fasce orarie.

### 7.2.3 Grafico errori

Sempre in relazione agli obbiettivi del seguente progetto (manutenzione, efficienza e risparmio),

è stato inserito un grafico per il tracciamento degli errori, in funzione del loro codice.

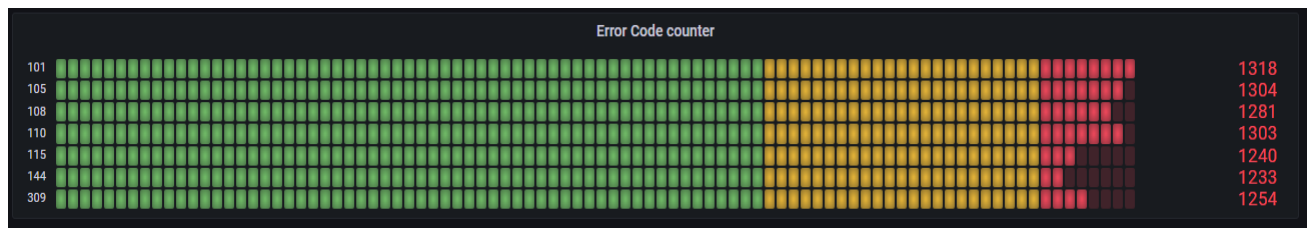
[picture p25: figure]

Figura 7.13 Grafico per il conteggio degli errori

Spesso, in un impianto di produzione, si possono verificare svariati errori. Di norma si tende a

sistemare il problema senza preoccuparsi di come cercare di evitarlo.

Con un tracciamento del numero degli errori in funzione del loro codice, è possibile controllare

quali errori si verificano più spesso in modo da poter agire di conseguenza.

Nel grafico sono stati aggiunti degli indicatori visivi che permettono di verificare quando un

certo errore si verifica più o meno spesso degli altri, suddividendoli in tre colori.

Grazie a questo sistema è possibile ridurre i fermi macchina ed incrementare la produzione con

un notevole risparmio sui costi di manutenzione/riparazione.

### 7.3 Servizio

I servizi in Angular sono dei componenti a sé stanti, che svolgono delle operazioni.

Essenzialmente sono degli oggetti che includono al loro interno delle funzioni javascript, che

possono essere richiamate dai vari componenti, dopo che sono stati importati in questi.

L’importazione avviene tramite il meccanismo del dependency injection, un design pattern

tipico della programmazione orientata agli oggetti.

In Angular si tratta di un meccanismo per cui Angular stesso, si occupa di creare ed iniettare

un'istanza del servizio all'interno del componente.

Per questo motivo la classe deve avere il decoratore @Injectable():

Figura 7.14: Esempio utilizzo Injectable

### 7.3.1 Richiesta dati

Il servizio, in questo caso, si occupa di effettuare le richieste GET al server e di fornire i dati agli

altri componenti del front-end attraverso il metodo getDati():

Figura 7.15: Metodo per richiesta dati al server

Linea 1: viene specificato l’URL del server a cui effettuare le richieste

Linea 2: viene definita una variabile di tipo Subject, la quale permette di bloccare il meccanismo

del polling tramite la funzione descritta in figura 7.16

Linea 4: viene importata un’istanza del modulo HttpClient all’interno della variabile http

Linee 6-12: Il metodo ritorna un Observable contenente la risposta alla richiesta HTTP effettuata

al server nella URL indicata. In particolare viene effettuato un polling di richieste ogni 1000ms

attraverso il metodo timer che presenta la seguente struttura:

- timer(x, y): Funzione che permette di impostare un intervallo di x millisecondi la prima

volta e y millisecondi tra una richiesta e l'altra

- switchMap: trasforma un input Observable in un altro Observable, nel nostro caso,

trasformeremo ogni numero emesso dal timer in una richiesta HTTP al backend

- retry(n): Risottoscrive su un errore n volte, se il campo è vuoto lo farà all'infinito
- share(): Per default, gli Observables RxJs creano un nuovo task per ogni subscriber

mentre si verifica la subcription. Nel nostro caso, tre subscribers finirebbero per creare

un'istanza del meccanismo di polling 3 volte, quindi 3 richieste HTTP. L'operatore

share() assicura che ogni subscriber utilizzi lo stesso polling.

- takeUntil(...): Per fermare un Observable stream mentre sta emettendo (es. componente

distrutto).

Successivamente, ogni volta che si cambia schermata, e si passa quindi ad un altro componente,

quel componente viene distrutto e tutti i suoi dati vengono eliminati. Quindi in questo caso non

ha senso lasciare il polling delle richieste attivo, per cui è buona norma fermarlo attraverso il

metodo precedentemente citato:

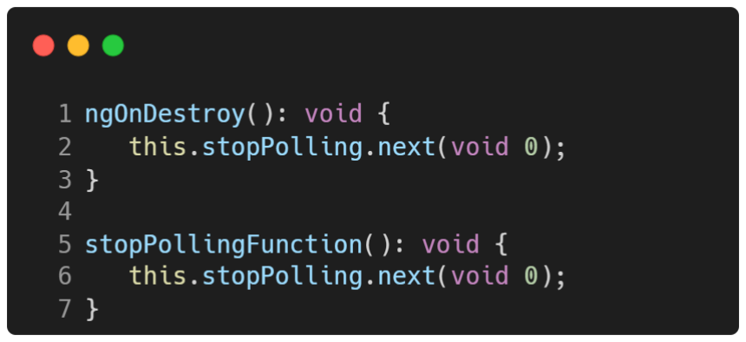
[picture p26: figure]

Figura 7.16: Metodi per fermare il polling

Linee 1-3: Metodo per effettuare uno stop del polling dopo l’evento di distruzione del

componente.

Linee 5-7: Metodo per effettuare uno stop del polling quando necessario, differisce dal

precedente, per la possibilità di essere chiamato da altri componenti.

## 8 Conclusioni e sviluppi futuri

L’elaborato ed il progetto stesso, mostrano in maniera esaustiva lo scopo principale e basilare

dell’obbiettivo posto inizialmente, il monitoraggio di uno o più sistemi di produzione industriale

attraverso dispositivi IoT.

Il progetto ha comportato diverse sfide, ma la sfida più grande è stata sicuramente lo studio e

l’apprendimento di diversi linguaggi e framework. Questo ha portato alcune difficoltà in fase di

sviluppo, il dover unire diversi livelli applicativi è risultato inizialmente molto complicato, ma

grazie ad una community online ben attiva ed a diversi tutorial e corsi, sempre online, è stato

possibile portare a termine il progetto e renderlo perfettamente funzionante. Inoltre grazie alla

modularità del progetto ed alla presenza di alcuni software (Postman) è stato possibile

scorporare i tre livelli applicativi e lavorare separatamente su ognuno di essi semplificando il

lavoro.

Nonostante ciò, i possibili sviluppi futuri legati a questa tecnologia e applicazione, sono

pressoché illimitati. Un’interessante sviluppo potrebbe essere quello legato all’autenticazione,

attraverso la quale gestire l’accesso di più aziende. Attualmente il sistema è pensato per lavorare

in locale su una rete aziendale privata, per cui non si pone il problema, ma nel caso di utilizzo di

servizi di hosting pubblici si rende necessaria l’autenticazione.

Un altro progetto interessante potrebbe essere quello di permette di interagire con la macchina,

impostando alcuni parametri, non critici, direttamente da remoto. Questa possibilità potrebbe

ampliare notevolmente la platea di utilizzatori.

A questa però è da aggiungere un livello di protezione robusto ed efficace. Nel caso di sola

lettura dei dati, il problema non si pone in quanto i dati per quanto possano essere strutturati non

sono per niente sensibili, non contengono informazioni riservate, ma aggiungendo la possibilità

di interagire con il macchinario le probabilità di arrecare danno, aumentano esponenzialmente.

Non solo è possibile modificare parametri del macchinario, comportando dei danni economici,

ma soprattutto si mette a rischio la salute e l’incolumità degli operatori (allagamenti, incendi,

schiacciamenti, infortuni…).

Uno sviluppo meno “delicato” ma altrettanto interessante, potrebbe essere quello relativo alla

standardizzazione dell’hardware/firmware.

È risaputo, che quando un qualcosa viene reso standard, questo permette risparmi di tempo,

fatica e quindi di denaro. La soluzione potrebbe essere quella di implementare, nel modulo per la comunicazione wifi (il microcontrollore ESP32), un protocollo standard per la comunicazione

con i PLC.

La maggior parte dei macchinari industriali, sono oggi comandati da PLC. I PLC per comunicare

tra di loro, o con sistemi esterni, utilizzano un protocollo che oramai è diventato uno standard di

fatto per l’automazione industriale. Il protocollo MODBUS RTU.

Dotando, per l’appunto, il microcontrollore, con questo protocollo non sarà nemmeno più

necessario implementare un hardware dedicato per ogni impianto produttivo (come invece è

stato fatto nel progetto) ma sarà necessario soltanto dotare l’hardware di una porta RS232 o

RS485 per comunicare in seriale con il PLC ed implementare a livello firmware tutti i comandi

necessari per leggere ed eventualmente scrivere sul PLC (questi comandi di norma sono forniti

dal costruttore del macchinario).

In conclusione, l’effort apportato per la realizzazione del progetto è sicuramente non trascurabile

ma grazie a questo è stato possibile entrare nel dettaglio di ogni livello applicativo, dall’hardware

al front-end, potendo così creare un sistema che fosse del tutto flessibile e fatto appositamente

per lo scopo per cui è stato ideato. Inoltre ha permesso lo studio e l’apprendimento di tecnologie,

oggi, utilizzatissime a livello lavorativo consentendo quindi di ampliare notevolmente il portfolio

delle capacità, necessarie per immettersi nel mondo lavorativo.
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

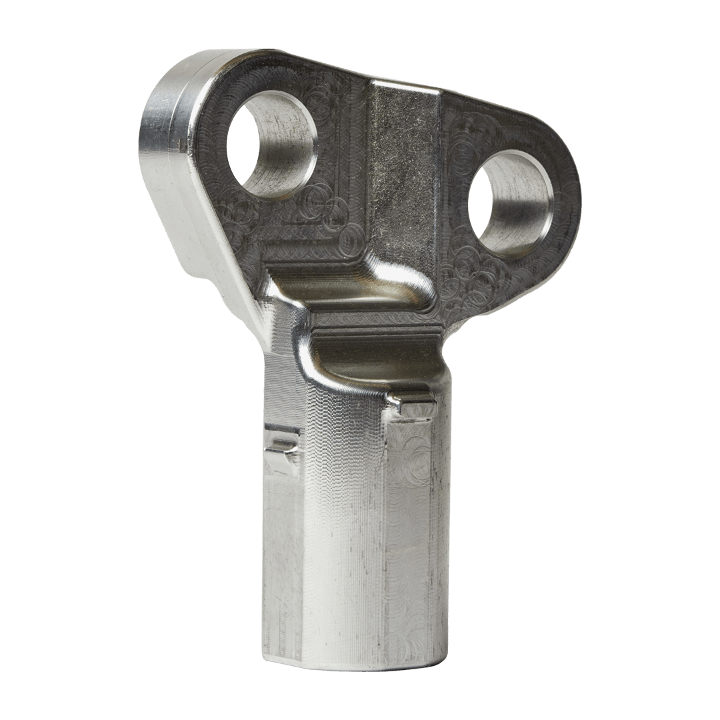
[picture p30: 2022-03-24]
Frontend/angular-app/src/assets/productImage/chiave-disasse.png

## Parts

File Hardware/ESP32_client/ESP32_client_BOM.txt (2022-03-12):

Date:	21/02/2022 11:24					
Tool:	Eeschema (5.1.5)-3					
Component Count:	115					
						
Individual Components:						
						
Item	Qty	Reference(s)	Value	LibPart	Footprint	Datasheet
		C1	100nF	Device:C_Small	Capacitor_SMD:C_0603_1608Metric	~
		C2	100uF	Device:CP1_Small		~
		C3	220nF_MKP-X2	Device:CP1	Capacitor_THT:CP_Radial_D4.0mm_P2.00mm	~
		C4	220nF_MKP-X2	Device:CP1	Capacitor_THT:CP_Radial_D4.0mm_P2.00mm	~
		C5	10uF	Device:CP1	Capacitor_THT:CP_Radial_D4.0mm_P2.00mm	~
		C6	100nF	Device:C_Small	Capacitor_SMD:C_0603_1608Metric	~
		C7	100nF	Device:C_Small	Capacitor_SMD:C_0603_1608Metric	~
		C8	100nF	Device:C_Small	Capacitor_SMD:C_0603_1608Metric	~
		C9	100nF	Device:C_Small	Capacitor_SMD:C_0603_1608Metric	~
		C10	100nF	Device:C_Small	Capacitor_SMD:C_0603_1608Metric	~
		C11	100nF	Device:C_Small	Capacitor_SMD:C_0603_1608Metric	~
		C12	100nF	Device:C_Small	Capacitor_SMD:C_0603_1608Metric	~
		C13	100nF	Device:C_Small	Capacitor_SMD:C_0603_1608Metric	~
		C14	10uF	Device:CP1	Capacitor_THT:CP_Radial_D4.0mm_P2.00mm	~
		C15	10uF	Device:CP1	Capacitor_THT:CP_Radial_D4.0mm_P2.00mm	~
		C16	100nF	Device:C_Small	Capacitor_SMD:C_0603_1608Metric	~
		C17	100nF	Device:C_Small	Capacitor_SMD:C_0603_1608Metric	~
		C18	100nF	Device:C_Small	Capacitor_SMD:C_0603_1608Metric	~
		C19	100nF	Device:C_Small	Capacitor_SMD:C_0603_1608Metric	~
		C20	100nF	Device:C_Small	Capacitor_SMD:C_0603_1608Metric	~
		C21	100nF	Device:CP1	Capacitor_THT:CP_Radial_D4.0mm_P2.00mm	~
		C22	100nF	Device:C_Small	Capacitor_SMD:C_0603_1608Metric	~
		C23	1uF	Device:CP1	Capacitor_THT:CP_Radial_D4.0mm_P2.00mm	~
		C24	100nF	Device:C_Small	Capacitor_SMD:C_0603_1608Metric	~
		C25	100nF	Device:C_Small	Capacitor_SMD:C_0603_1608Metric	~
		C26	100uF	Device:CP1	Capacitor_THT:CP_Radial_D4.0mm_P2.00mm	~
		C27	100nF	Device:C_Small	Capacitor_SMD:C_0603_1608Metric	~
		C28	100nF	Device:C_Small	Capacitor_SMD:C_0603_1608Metric	~
		C29	100nF	Device:C_Small	Capacitor_SMD:C_0603_1608Metric	~
		C30	100nF	Device:C_Small	Capacitor_SMD:C_0603_1608Metric	~
		D1	BAV99	Diode:BAV99	Package_TO_SOT_SMD:SOT-23	https://assets.nexperia.com/documents/data-sheet/BAV99_SER.pdf
		D2	ledGreenPos1	Device:LED	LED_SMD:LED_0805_2012Metric	~
		D3	LED_5v	Device:LED	LED_SMD:LED_0805_2012Metric	~
		D4	ledGreenPos2	Device:LED	LED_SMD:LED_0805_2012Metric	~
		D5	ledGreenPos3	Device:LED	LED_SMD:LED_0805_2012Metric	~
		D6	ledRedPos1	Device:LED	LED_SMD:LED_0805_2012Metric	~
		D7	LED_3.3v	Device:LED	LED_SMD:LED_0805_2012Metric	~
		D8	ledRedPos2	Device:LED	LED_SMD:LED_0805_2012Metric	~
		D9	ledRedPos3	Device:LED	LED_SMD:LED_0805_2012Metric	~
		H1	MountingHole	Mechanical:MountingHole	MountingHole:MountingHole_3.2mm_M3	~
		H2	MountingHole	Mechanical:MountingHole	MountingHole:MountingHole_3.2mm_M3	~
		H3	MountingHole	Mechanical:MountingHole	MountingHole:MountingHole_3.2mm_M3	~
		H4	MountingHole	Mechanical:MountingHole	MountingHole:MountingHole_3.2mm_M3	~
		J1	Jack_12v_DC	Connector:Barrel_Jack_Switch	Librerie_LEO:jack_alimentazione_switchcraft	~
		J2	ingresso Vcc	Connector:Screw_Terminal_01x02	Librerie_LEO:morsetto_2vie_grande	~
		J3	Motor OUT	Connector:Screw_Terminal_01x02		~
		J4	PNP_proximity0	Connector:Screw_Terminal_01x03		~
		J5	PNP_proximity2	Connector:Screw_Terminal_01x03		~
		J6	PNP_proximity1	Connector:Screw_Terminal_01x03		~
		J7	PNP_proximity3	Connector:Screw_Terminal_01x03		~
		K1	SANYOU_SRD_Form_A	Relay:SANYOU_SRD_Form_A	Relay_THT:Relay_SPST_SANYOU_SRD_Series_Form_A	http://www.sanyourelay.ca/public/products/pdf/SRD.pdf
		L1	6/8mH_modo comune	Device:L_Core_Ferrite_Coupled_Small		~
		Q1	BC817	Transistor_BJT:BC817	Package_TO_SOT_SMD:SOT-23	http://www.fairchildsemi.com/ds/BC/BC817.pdf
		Q2	BC817	Transistor_BJT:BC817	Package_TO_SOT_SMD:SOT-23	http://www.fairchildsemi.com/ds/BC/BC817.pdf
		Q3	BC817	Transistor_BJT:BC817	Package_TO_SOT_SMD:SOT-23	http://www.fairchildsemi.com/ds/BC/BC817.pdf
		Q4	BC817	Transistor_BJT:BC817	Package_TO_SOT_SMD:SOT-23	http://www.fairchildsemi.com/ds/BC/BC817.pdf
		Q5	BC817	Transistor_BJT:BC817	Package_TO_SOT_SMD:SOT-23	http://www.fairchildsemi.com/ds/BC/BC817.pdf
		Q6	BC817	Transistor_BJT:BC817	Package_TO_SOT_SMD:SOT-23	http://www.fairchildsemi.com/ds/BC/BC817.pdf
		Q7	BC817	Transistor_BJT:BC817	Package_TO_SOT_SMD:SOT-23	http://www.fairchildsemi.com/ds/BC/BC817.pdf
		R1	1K	Device:R	Resistor_SMD:R_0603_1608Metric	~
		R2	10K	Device:R	Resistor_SMD:R_0603_1608Metric	~
		R3	4,7R	Device:R	Resistor_SMD:R_0603_1608Metric	~
		R4	1K	Device:R	Resistor_SMD:R_0603_1608Metric	~
		R5	10K	Device:R	Resistor_SMD:R_0603_1608Metric	~
		R6	1K	Device:R	Resistor_SMD:R_0603_1608Metric	~
		R7	1K	Device:R	Resistor_SMD:R_0603_1608Metric	~
		R8	1K	Device:R	Resistor_SMD:R_0603_1608Metric	~
		R9	10K	Device:R	Resistor_SMD:R_0603_1608Metric	~
		R10	10K	Device:R	Resistor_SMD:R_0603_1608Metric	~
		R11	1K	Device:R	Resistor_SMD:R_0603_1608Metric	~
		R12	10K	Device:R	Resistor_SMD:R_0603_1608Metric	~
		R13	1K	Device:R	Resistor_SMD:R_0603_1608Metric	~
		R14	1K	Device:R	Resistor_SMD:R_0603_1608Metric	~
		R15	27K	Device:R	Resistor_SMD:R_0603_1608Metric	~
		R16	27K	Device:R	Resistor_SMD:R_0603_1608Metric	~
		R17	1K	Device:R	Resistor_SMD:R_0603_1608Metric	~
		R18	10K	Device:R	Resistor_SMD:R_0603_1608Metric	~
		R19	1K	Device:R	Resistor_SMD:R_0603_1608Metric	~
		R20	15K	Device:R	Resistor_SMD:R_0603_1608Metric	~
		R21	1K	Device:R	Resistor_SMD:R_0603_1608Metric	~
		R22	15K	Device:R	Resistor_SMD:R_0603_1608Metric	~
		R23	1K	Device:R	Resistor_SMD:R_0603_1608Metric	~
		R24	10K	Device:R	Resistor_SMD:R_0603_1608Metric	~
		R25	10K	Device:R	Resistor_SMD:R_0603_1608Metric	~
		R26	1K	Device:R	Resistor_SMD:R_0603_1608Metric	~
		R27	1K	Device:R	Resistor_SMD:R_0603_1608Metric	~
		R28	1K	Device:R	Resistor_SMD:R_0603_1608Metric	~
		R29	10K	Device:R	Resistor_SMD:R_0603_1608Metric	~
		R30	1K	Device:R	Resistor_SMD:R_0603_1608Metric	~
		R31	1K	Device:R	Resistor_SMD:R_0603_1608Metric	~
		R32	1K	Device:R	Resistor_SMD:R_0603_1608Metric	~
		R33	10K	Device:R	Resistor_SMD:R_0603_1608Metric	~
		R34	27K	Device:R	Resistor_SMD:R_0603_1608Metric	~
		R35	27K	Device:R	Resistor_SMD:R_0603_1608Metric	~
		R36	1K	Device:R	Resistor_SMD:R_0603_1608Metric	~
		R37	1K	Device:R	Resistor_SMD:R_0603_1608Metric	~
		R38	15K	Device:R	Resistor_SMD:R_0603_1608Metric	~
		R39	1K	Device:R	Resistor_SMD:R_0603_1608Metric	~
		R40	15K	Device:R	Resistor_SMD:R_0603_1608Metric	~
		R41	1K	Device:R	Resistor_SMD:R_0603_1608Metric	~
		R42	10K	Device:R	Resistor_SMD:R_0603_1608Metric	~
		R43	10K	Device:R	Resistor_SMD:R_0603_1608Metric	~
		R44	10K	Device:R	Resistor_SMD:R_0603_1608Metric	~
		R45	1K	Device:R	Resistor_SMD:R_0603_1608Metric	~
		R46	1K	Device:R	Resistor_SMD:R_0603_1608Metric	~
		R47	1K	Device:R	Resistor_SMD:R_0603_1608Metric	~
		SW1	Start	Switch:SW_Push		~
		SW2	Start	Switch:SW_Push		~
		U1	ESP32_devkit_V1_30pin	Librerie_LEO:ESP32_devkit_V1_30pin		
		U2	AMS1117-5.0	Regulator_Linear:AMS1117-5.0	Package_TO_SOT_SMD:SOT-223-3_TabPin2	http://www.advanced-monolithic.com/pdf/ds1117.pdf
		U3	LM1117-3.3	Regulator_Linear:LM1117-3.3	Package_TO_SOT_SMD:SOT-223-3_TabPin2	http://www.ti.com/lit/ds/symlink/lm1117.pdf
		U4	SFH618x	Librerie_LEO:SFH618x		
		U5	SFH618x	Librerie_LEO:SFH618x		
		U6	SFH618x	Librerie_LEO:SFH618x		
		U7	SFH618x	Librerie_LEO:SFH618x		

Collated Components:						
						
Item	Qty	Reference(s)	Value	LibPart	Footprint	Datasheet
1	21	C1, C6, C7, C8, C9, C10, C11, C12, C13, C16, C17, C18, C19, C20, C22, C24, C25, C27, C28, C29, C30	100nF	Device:C_Small	Capacitor_SMD:C_0603_1608Metric	~
2	1	C2	100uF	Device:CP1_Small		~
3	2	C3, C4	220nF_MKP-X2	Device:CP1	Capacitor_THT:CP_Radial_D4.0mm_P2.00mm	~
4	3	C5, C14, C15	10uF	Device:CP1	Capacitor_THT:CP_Radial_D4.0mm_P2.00mm	~
5	1	C21	100nF	Device:CP1	Capacitor_THT:CP_Radial_D4.0mm_P2.00mm	~
6	1	C23	1uF	Device:CP1	Capacitor_THT:CP_Radial_D4.0mm_P2.00mm	~
7	1	C26	100uF	Device:CP1	Capacitor_THT:CP_Radial_D4.0mm_P2.00mm	~
8	1	D1	BAV99	Diode:BAV99	Package_TO_SOT_SMD:SOT-23	https://assets.nexperia.com/documents/data-sheet/BAV99_SER.pdf
9	1	D2	ledGreenPos1	Device:LED	LED_SMD:LED_0805_2012Metric	~
10	1	D3	LED_5v	Device:LED	LED_SMD:LED_0805_2012Metric	~
11	1	D4	ledGreenPos2	Device:LED	LED_SMD:LED_0805_2012Metric	~
12	1	D5	ledGreenPos3	Device:LED	LED_SMD:LED_0805_2012Metric	~
13	1	D6	ledRedPos1	Device:LED	LED_SMD:LED_0805_2012Metric	~
14	1	D7	LED_3.3v	Device:LED	LED_SMD:LED_0805_2012Metric	~
15	1	D8	ledRedPos2	Device:LED	LED_SMD:LED_0805_2012Metric	~
16	1	D9	ledRedPos3	Device:LED	LED_SMD:LED_0805_2012Metric	~
17	4	H1, H2, H3, H4	MountingHole	Mechanical:MountingHole	MountingHole:MountingHole_3.2mm_M3	~
18	1	J1	Jack_12v_DC	Connector:Barrel_Jack_Switch	Librerie_LEO:jack_alimentazione_switchcraft	~
19	1	J2	ingresso Vcc	Connector:Screw_Terminal_01x02	Librerie_LEO:morsetto_2vie_grande	~
20	1	J3	Motor OUT	Connector:Screw_Terminal_01x02		~
21	1	J4	PNP_proximity0	Connector:Screw_Terminal_01x03		~
22	1	J5	PNP_proximity2	Connector:Screw_Terminal_01x03		~
23	1	J6	PNP_proximity1	Connector:Screw_Terminal_01x03		~
24	1	J7	PNP_proximity3	Connector:Screw_Terminal_01x03		~
25	1	K1	SANYOU_SRD_Form_A	Relay:SANYOU_SRD_Form_A	Relay_THT:Relay_SPST_SANYOU_SRD_Series_Form_A	http://www.sanyourelay.ca/public/products/pdf/SRD.pdf
26	1	L1	6/8mH_modo comune	Device:L_Core_Ferrite_Coupled_Small		~
27	7	Q1, Q2, Q3, Q4, Q5, Q6, Q7	BC817	Transistor_BJT:BC817	Package_TO_SOT_SMD:SOT-23	http://www.fairchildsemi.com/ds/BC/BC817.pdf
28	25	R1, R4, R6, R7, R8, R11, R13, R14, R17, R19, R21, R23, R26, R27, R28, R30, R31, R32, R36, R37, R39, R41, R45, R46, R47	1K	Device:R	Resistor_SMD:R_0603_1608Metric	~
29	13	R2, R5, R9, R10, R12, R18, R24, R25, R29, R33, R42, R43, R44	10K	Device:R	Resistor_SMD:R_0603_1608Metric	~
30	1	R3	4,7R	Device:R	Resistor_SMD:R_0603_1608Metric	~
31	4	R15, R16, R34, R35	27K	Device:R	Resistor_SMD:R_0603_1608Metric	~
32	4	R20, R22, R38, R40	15K	Device:R	Resistor_SMD:R_0603_1608Metric	~
33	2	SW1, SW2	Start	Switch:SW_Push		~
34	1	U1	ESP32_devkit_V1_30pin	Librerie_LEO:ESP32_devkit_V1_30pin		
35	1	U2	AMS1117-5.0	Regulator_Linear:AMS1117-5.0	Package_TO_SOT_SMD:SOT-223-3_TabPin2	http://www.advanced-monolithic.com/pdf/ds1117.pdf
36	1	U3	LM1117-3.3	Regulator_Linear:LM1117-3.3	Package_TO_SOT_SMD:SOT-223-3_TabPin2	http://www.ti.com/lit/ds/symlink/lm1117.pdf
37	4	U4, U5, U6, U7	SFH618x	Librerie_LEO:SFH618x

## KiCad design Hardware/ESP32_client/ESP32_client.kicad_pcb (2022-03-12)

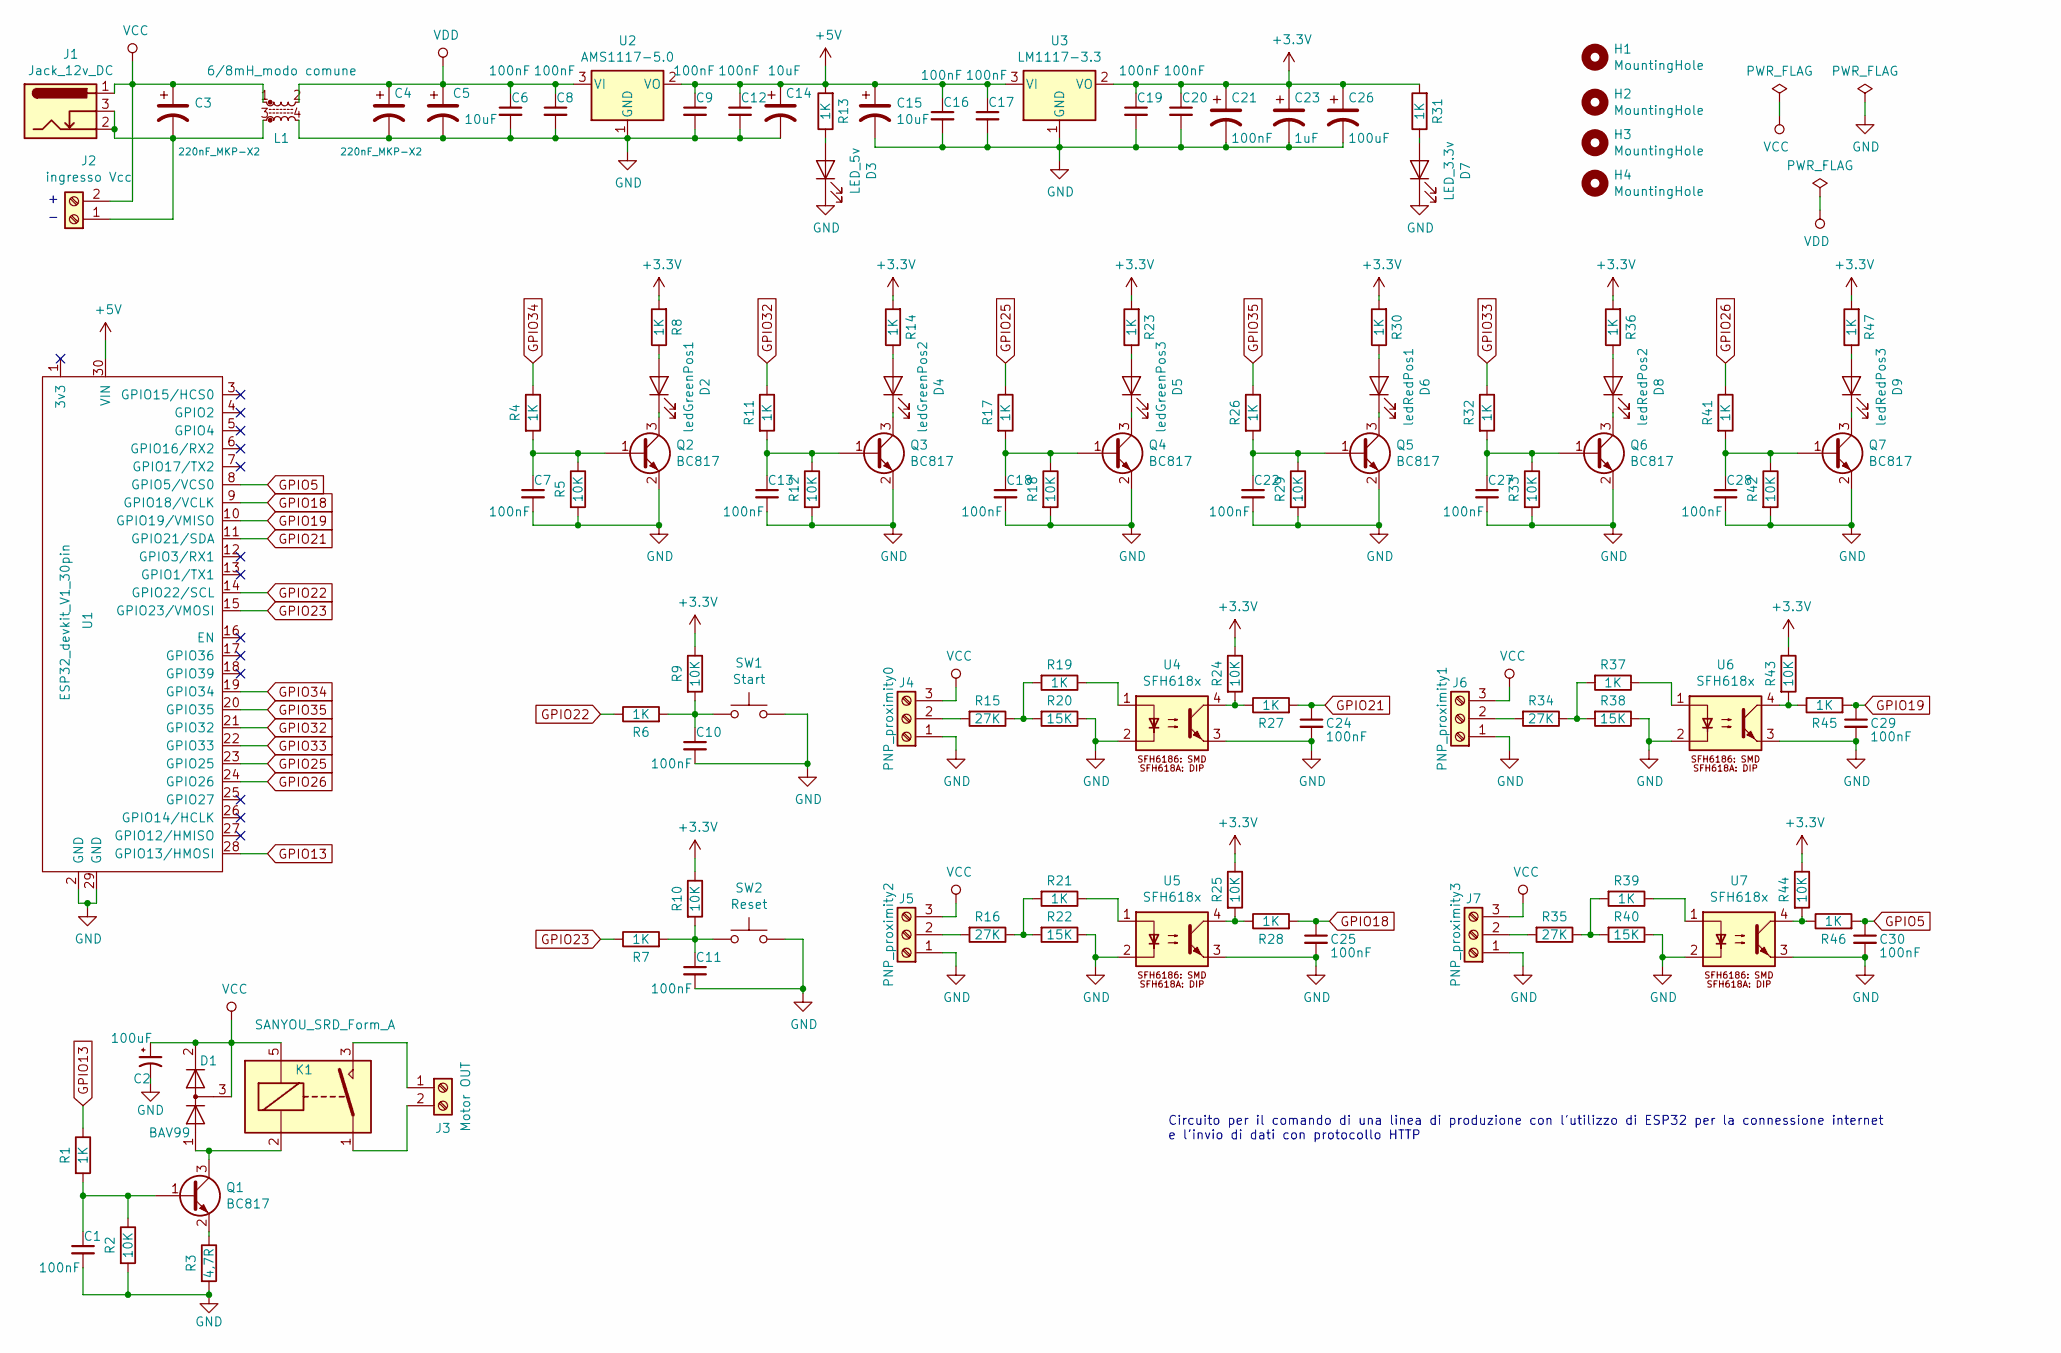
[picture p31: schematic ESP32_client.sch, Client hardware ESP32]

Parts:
C1, C6, C7, C8, C9, C10, C11, C12, C13, C16, C17, C18, C19, C20, C22, C24, C25, C27, C28, C29, C30: 100nF; C_0603_1608Metric
C2: 100uF; CP_Radial_D5.0mm_P2.50mm
C3, C4: 220nF_MKP-X2; C_Rect_L18.0mm_W7.0mm_P15.00mm_FKS3_FKP3
C5, C14, C15: 10uF; CP_Radial_D4.0mm_P2.00mm
C21: 100nF; CP_Radial_D4.0mm_P2.00mm
C23: 1uF; CP_Radial_D4.0mm_P2.00mm
C26: 100uF; CP_Radial_D4.0mm_P2.00mm
D1: BAV99; SOT-23
D2: ledGreenPos1; LED_0805_2012Metric
D3: LED_5v; LED_0805_2012Metric
D4: ledGreenPos2; LED_0805_2012Metric
D5: ledGreenPos3; LED_0805_2012Metric
D6: ledRedPos1; LED_0805_2012Metric
D7: LED_3.3v; LED_0805_2012Metric
D8: ledRedPos2; LED_0805_2012Metric
D9: ledRedPos3; LED_0805_2012Metric
H1, H2, H3, H4: MountingHole; MountingHole_3.2mm_M3
J1: Jack_12v_DC; jack_alimentazione_switchcraft
J2: ingresso Vcc; morsetto_2vie_P10.0mm
J3: Motor OUT; morsetto_2vie_P10.0mm
J4: PNP_proximity0; TerminalBlock_bornier-3_P5.08mm
J5: PNP_proximity2; TerminalBlock_bornier-3_P5.08mm
J6: PNP_proximity1; TerminalBlock_bornier-3_P5.08mm
J7: PNP_proximity3; TerminalBlock_bornier-3_P5.08mm
K1: SANYOU_SRD_Form_A; Relay_SPST_SANYOU_SRD_Series_Form_A
L1: 6/8mH_modo comune; Choke_Schaffner_RN204-04-9.0x14.0mm
Q1, Q2, Q3, Q4, Q5, Q6, Q7: BC817; SOT-23
R1, R4, R6, R7, R8, R11, R13, R14, R17, R19, R21, R23, R26, R27, R28, R30, R31, R32, R36, R37, R39, R41, R45, R46, R47: 1K; R_0603_1608Metric
R2, R5, R9, R10, R12, R18, R24, R25, R29, R33, R42, R43, R44: 10K; R_0603_1608Metric
R3: 4,7R; R_0603_1608Metric
R15, R16, R34, R35: 27K; R_0603_1608Metric
R20, R22, R38, R40: 15K; R_0603_1608Metric
SW1: Start; SW_PUSH_6mm
SW2: Reset; SW_PUSH_6mm
U1: ESP32_devkit_V1_30pin; esp32_devkit_v1_doit
U2: AMS1117-5.0; SOT-223-3_TabPin2
U3: LM1117-3.3; SOT-223-3_TabPin2
U4, U5, U6, U7: SFH618x; DIP-4_W7.62mm

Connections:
+3V3: C19.1, C20.1, C21.1, C23.1, C26.1, R8.2, R9.1, R10.1, R14.2, R23.2, R24.1, R25.1, R30.2, R31.2, R36.2, R43.1, R44.1, R47.2, U3.2 (VO)
+5V: C9.1, C12.1, C14.1, C15.1, C16.1, C17.1, R13.2, U1.30 (VIN), U2.2 (VO), U3.3 (VI)
GND: C1.2, C2.2, C4.2, C5.2, C6.2, C7.2, C8.2, C9.2, C10.2, C11.2, C12.2, C13.2, C14.2, C15.2, C16.2, C17.2, C18.2, C19.2, C20.2, C21.2, C22.2, C23.2, C24.2, C25.2, C26.2, C27.2, C28.2, C29.2, C30.2, D3.1 (K), D7.1 (K), J4.1, J5.1, J6.1, J7.1, L1.4, Q2.2 (E), Q3.2 (E), Q4.2 (E), Q5.2 (E), Q6.2 (E), Q7.2 (E), R2.2, R3.2, R5.2, R12.2, R18.2, R20.1, R22.1, R29.2, R33.2, R38.1, R40.1, R42.2, SW1.2, SW2.2, U1.2 (GND), U1.29 (GND), U2.1 (GND), U3.1 (GND), U4.2, U4.3, U5.2, U5.3, U6.2, U6.3, U7.2, U7.3
GPIO5: C30.1, R46.2, U1.8 (GPIO5/VCS0)
GPIO13: R1.1, U1.28 (GPIO13/HMOSI)
GPIO18: C25.1, R28.2, U1.9 (GPIO18/VCLK)
GPIO19: C29.1, R45.2, U1.10 (GPIO19/VMISO)
GPIO21: C24.1, R27.2, U1.11 (GPIO21/SDA)
GPIO22: R6.1, U1.14 (GPIO22/SCL)
GPIO23: R7.1, U1.15 (GPIO23/VMOSI)
GPIO25: R17.1, U1.23 (GPIO25)
GPIO26: R41.1, U1.24 (GPIO26)
GPIO32: R11.1, U1.21 (GPIO32)
GPIO33: R32.1, U1.22 (GPIO33)
GPIO34: R4.1, U1.19 (GPIO34)
GPIO35: R26.1, U1.20 (GPIO35)
unnamed: C1.1, Q1.1 (B), R1.2, R2.1
unnamed: C3.2, J1.2, J1.3, J2.1, L1.3
unnamed: C7.1, Q2.1 (B), R4.2, R5.1
unnamed: C10.1, R6.2, R9.2, SW1.1
unnamed: C11.1, R7.2, R10.2, SW2.1
unnamed: C13.1, Q3.1 (B), R11.2, R12.1
unnamed: C18.1, Q4.1 (B), R17.2, R18.1
unnamed: C22.1, Q5.1 (B), R26.2, R29.1
unnamed: C27.1, Q6.1 (B), R32.2, R33.1
unnamed: C28.1, Q7.1 (B), R41.2, R42.1
unnamed: D1.1 (K), K1.2, Q1.3 (C)
unnamed: D2.1 (K), Q2.3 (C)
unnamed: D2.2 (A), R8.1
unnamed: D3.2 (A), R13.1
unnamed: D4.1 (K), Q3.3 (C)
unnamed: D4.2 (A), R14.1
unnamed: D5.1 (K), Q4.3 (C)
unnamed: D5.2 (A), R23.1
unnamed: D6.1 (K), Q5.3 (C)
unnamed: D6.2 (A), R30.1
unnamed: D7.2 (A), R31.1
unnamed: D8.1 (K), Q6.3 (C)
unnamed: D8.2 (A), R36.1
unnamed: D9.1 (K), Q7.3 (C)
unnamed: D9.2 (A), R47.1
unnamed: J3.1, K1.3
unnamed: J3.2, K1.1
unnamed: J4.2, R15.2
unnamed: J5.2, R16.2
unnamed: J6.2, R34.2
unnamed: J7.2, R35.2
unnamed: Q1.2 (E), R3.1
unnamed: R15.1, R19.2, R20.2
unnamed: R16.1, R21.2, R22.2
unnamed: R19.1, U4.1
unnamed: R21.1, U5.1
unnamed: R24.2, R27.1, U4.4
unnamed: R25.2, R28.1, U5.4
unnamed: R34.1, R37.2, R38.2
unnamed: R35.1, R39.2, R40.2
unnamed: R37.1, U6.1
unnamed: R39.1, U7.1
unnamed: R43.2, R45.1, U6.4
unnamed: R44.2, R46.1, U7.4
VCC: C2.1, C3.1, D1.2 (A), D1.3 (K), J1.1, J2.2, J4.3, J5.3, J6.3, J7.3, K1.5, L1.1
VDD: C4.1, C5.1, C6.1, C8.1, L1.2, U2.3 (VI)

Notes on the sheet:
Circuito per il comando di una linea di produzione con l'utilizzo di ESP32 per la connessione internet e l'invio di dati con protocollo HTTP

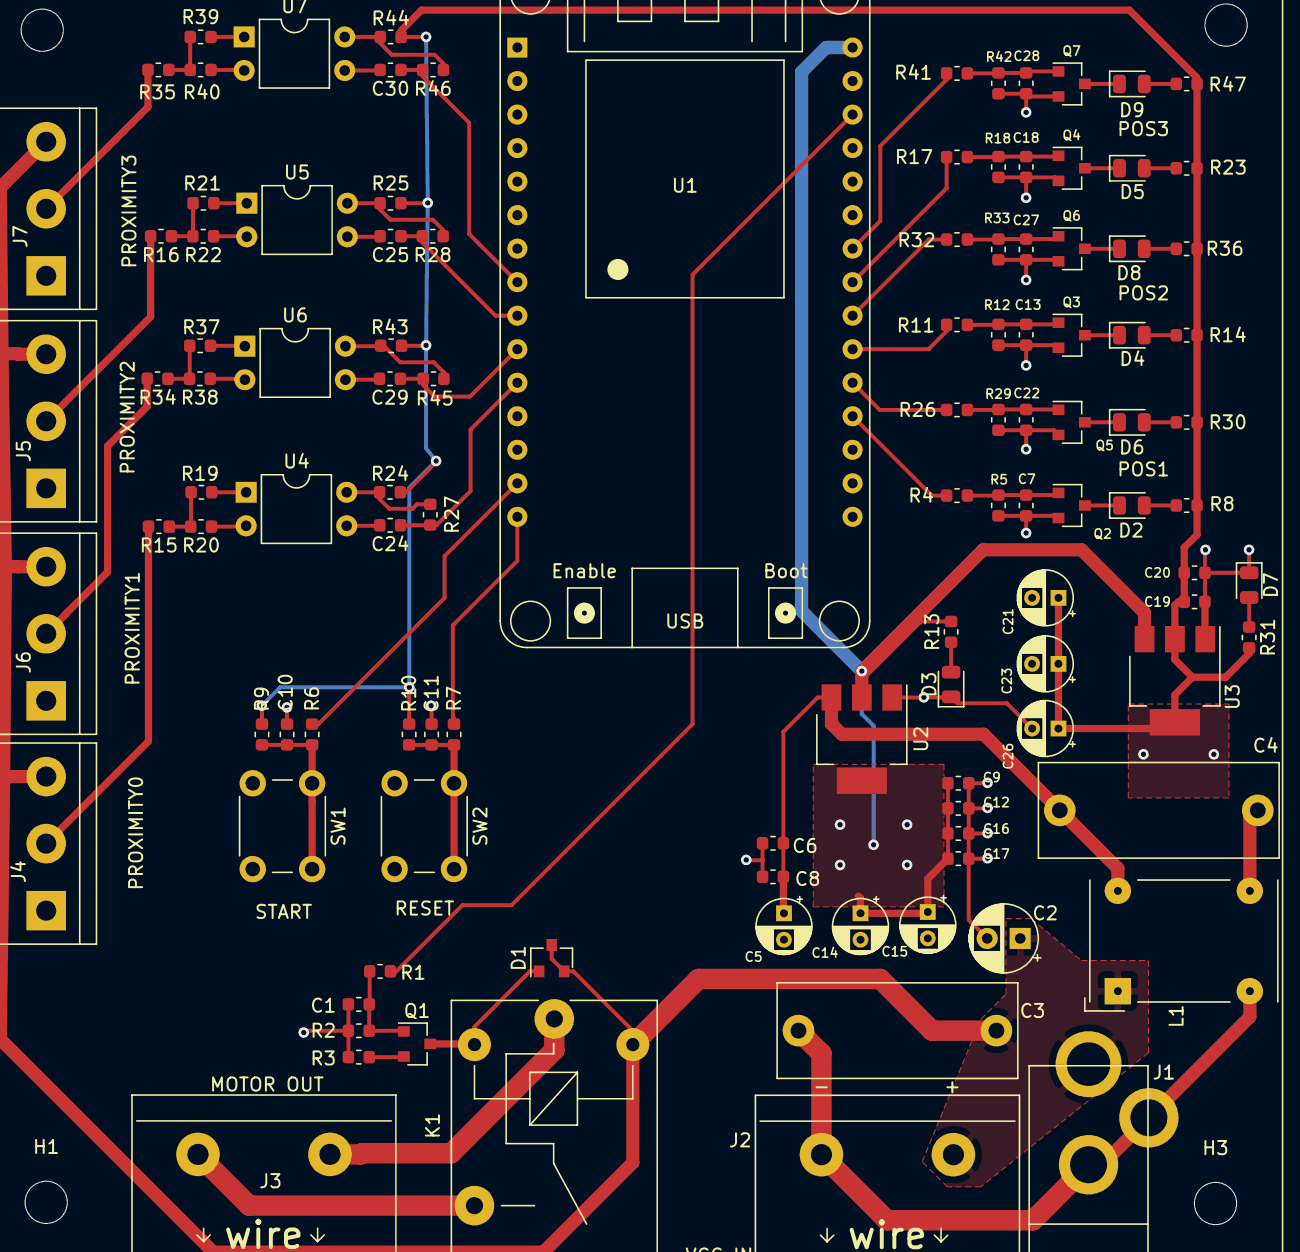
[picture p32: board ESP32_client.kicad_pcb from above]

Board: 2 copper layers, 115 parts (0 on the bottom side), 62 nets.

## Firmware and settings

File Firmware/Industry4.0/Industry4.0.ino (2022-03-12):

#include "globalVar.h"
#include "ledFunction.h"
#include "lineFunction.h"
#include "wifiFunction.h"

void setup() 
{
  Serial.begin(115200);

  Serial.println("Led setup");
  pinMode(ledGreenPos1, OUTPUT);
  pinMode(ledRedPos1, OUTPUT);
  pinMode(ledGreenPos2, OUTPUT);
  pinMode(ledRedPos2, OUTPUT);
  pinMode(ledGreenPos3, OUTPUT);
  pinMode(ledRedPos3, OUTPUT);
  ledOff();


  Serial.println("startButton setup");
  pinMode(startButton, INPUT);

  Serial.println("resetButton setup");
  attachInterrupt(resetButton, resetFunction, RISING);    //interrupt che si attiva ogni volta che lo stato passa da basso ad alto

  Serial.println("Proximity setup");
  pinMode(proximity0, INPUT);
  pinMode(proximity1, INPUT);
  pinMode(proximity2, INPUT);
  pinMode(proximity3, INPUT);
  
  connectESP();

  // Assegno l'id al macchinario
  idMachinery = generateIDMachinery();
}




void loop() 
{
  
  /*
   * Ad ogni stato macchina corrisponde l'avanzamento del pezzo nella linea di montaggio
   */

  currentMillis = millis(); //aggiorno tempo
  switch(stateMachine)
  {
    positionP = positions[stateMachine]; //specifico in quale postazione si trova il pezzo
    
    case 0: //accensione impianto ed attesa caricamento pezzo
      while(digitalRead(startButton) == LOW) //finchè il pulsante non è premuto
      {
        currentMillis = millis(); //aggiorno tempo
        idleStartingState();
        if(digitalRead(startButton) == HIGH && digitalRead(proximity0) == HIGH) //se il pulsante viene premuto e il pezzo è sul nastro
        {
          ledOff(); //spegni tutti i led
          
          //Assegno l'id al prodotto
          idProduct = generateIDProduct();     

          delay(50);
          
          motorON(); //accendi nastri linea
          stateMachine = 1; //vai alla postazione successiva 
          break;
        }
      }
      break;
      

    case 1: //pezzo caricato sta viaggiando sui nastri per arrivare alla postazione 1
      Serial.print(" . ");
      idleStartingState();   

      counter = 0;
      while(digitalRead(proximity1) == HIGH) //finchè il pezzo è presente sulla postazione 1
      {
        currentMillis = millis(); //aggiorno tempo
        motorOFF();
        Serial.println("Pezzo in lavorazioni nella postazione 1");

        if(counter > 5000 || resetState == HIGH) //circa 5 secondi di lavorazione o pulsante RESET premuto
        {
          if((random(0, 5000) > 2000 && flagError == LOW) || resetState == HIGH) //PASS/FAIL casuale o pulsante RESET premuto
          {
            Serial.println("Lavorazione OK, passaggio a stazione 2");
            pass = true;
            errorCode = 0;
            motorON();
            resetState = LOW; //riporto lo stato del pulsante di reset basso
            stateMachine = 2; //passa a postazione 2
            flagError = LOW; //Azzero il flag errori
            delay(2000); //Attendi che il pezzo si sposti dal proximity
            break;
          }
          else 
          {
            pass = false;
            flagError = HIGH;
            errorCode = generateErrorCode();
          }
          counter = 0;
        }
        workstationOne(flagError); //lampeggia i led secondo lo stato di flagError
        counter++;
      }//END while
      break; //stato1
    

    case 2: //il pezzo ha terminato la lavorazione 1 ed ora va nella postazione 2
      workstationOne(flagError);

      counter = 0;

      while(digitalRead(proximity2) == HIGH) //finchè il pezzo è presente sulla postazione 2
      {
        currentMillis = millis(); //aggiorno tempo
        motorOFF();
        Serial.println("Pezzo in lavorazione nella postazione 2");

        if(counter > 5000 || resetState == HIGH) //circa 5 secondi di lavorazione
        {
          if((random(0, 5000) > 2000 && flagError == LOW) || resetState == HIGH) //PASS/FAIL casuale o pulsante RESET premuto
          {
            Serial.println("Lavorazione OK, passaggio a stazione 3");
            pass = true;
            errorCode = 0;
            motorON();
            resetState = LOW; //riporto lo stato del pulsante di reset basso
            stateMachine = 3; //passa a postazione 3
            flagError = LOW; //Azzero il flag errori
            delay(2000); //Attendi che il pezzo si sposti dal proximity
            break;
          }
          else 
          {
            flagError = HIGH;
            pass = false;
            errorCode = generateErrorCode();
          }
          counter = 0;
        }
        workstationTwo(flagError); //lampeggia i led secondo lo stato di flagError
        counter++;       
      }
      break; //stato2
      

    case 3: //il pezzo ha terminato la lavorazione 2 ed ora va nella postazione 3
      workstationTwo(flagError);

      counter = 0;

      while(digitalRead(proximity3) == HIGH) //finchè il pezzo è presente sulla postazione 3
      {
        currentMillis = millis(); //aggiorno tempo
        motorOFF();
        Serial.println("Pezzo in lavorazione nella postazione 3");

        if(counter > 5000 || resetState == HIGH) //circa 5 secondi di lavorazione
        {
          if((random(0, 5000) > 2000 && flagError == LOW) || resetState == HIGH) //PASS/FAIL casuale o pulsante RESET premuto
          {
            Serial.println("Lavorazione OK, attesa uscita pezzo");
            pass = true;
            errorCode = 0;
            motorON();
            resetState = LOW; //riporto lo stato del pulsante di reset basso
            stateMachine = 4; //passa a stato 4 per attesa prelievo pezzo
            flagError = LOW; //Azzero il flag errori
            delay(2000); //Attendi che il pezzo si sposti dal proximity
            break;
          }
          else 
          {
            pass = false;
            flagError = HIGH;
            errorCode = generateErrorCode();
          }
          counter = 0;
        }
        workstationThree(flagError); //lampeggia i led secondo lo stato di flagError
        counter++;       
      }
      break; //stato3


      case 4:
        allLedGreenOn();
        counter = 0;

        while(digitalRead(proximity0) == HIGH) //pezzo prodotto, in attesa di estrazione 
        {
          Serial.println("Estrarre pezzo");
          if(digitalRead(proximity0) == LOW)
          {
            Serial.println("Pezzo estratto, caricare un nuovo pezzo");
            pass = true;
            errorCode = 0;
            stateMachine = 0;
          }
        }
        break; //stato4
  }//END SWITCH
}

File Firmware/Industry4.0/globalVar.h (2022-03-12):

/*
 * Dichiarazione delle variabili globali
 */

#define ledGreenPos1    34
#define ledRedPos1      35

#define ledGreenPos2    32
#define ledRedPos2      33

#define ledGreenPos3    25
#define ledRedPos3      26

#define startButton     22
#define resetButton     23

#define proximity0      21
#define proximity1      19
#define proximity2      18
#define proximity3      5

#define motor           13

unsigned long currentMillis = 0;
unsigned long previousMillis = 0;
int counter = 0; //contatore per tempo lavorazione pezzo

int blinkingTime = 200;
bool ledState = LOW; //flag per imporre lo stato ai led
bool flagError = LOW; //flag che segnala la presenza di errori lavorazione
bool resetState = LOW; //flag che segnala se il pulsante di reset allarmi è stato premuto

const char* ssid     = "yourSSID";  // -- PUT HERE YOUR WIFI SSID
const char* password = "yourPASSWORD"; // -- PUT HERE YOUR WIFI PASSWORD

int stateMachine = 0; //stato macchina per macchina a stati

/*
 * Indirizzo IP del server, che in questo caso è in locale sul pc, il quale
 * ha indirizzo IP 192.168.1.2, quindi bisogna specificare l'indirizzo IP
 * del pc e la porta sul quale lavora il server (oltre che la route)
 */

const String serverURL = "http://192.168.1.2:3000/produzione/inserisci"; // -- CHANGE IF NECESSARY THE HOST URL

// Dati mockati
String machineries[] = {"#001aude", "#002ufjd", "#003hghj", "#004hkhi", "#005fewe",
                        "#006dewf"};
String products[] = {"#df431", "#kg848", "#dp973", "#qa345", "#lg059",
                     "#ps374", "#oe385"};
String positions[] = {"Station 1: User load / unload",
                      "Station 2: CNC roughing",
                      "Station 3: Protective paint",
                      "Station 4: Laser Labeling"};
int errorCodes[] = {101, 105, 108, 110, 115, 144, 309};

// Variabili per dati da inviare al server
String idMachinery = "";
String idProduct = "";
String positionP = "";
boolean pass = true;
int errorCode = 200;
